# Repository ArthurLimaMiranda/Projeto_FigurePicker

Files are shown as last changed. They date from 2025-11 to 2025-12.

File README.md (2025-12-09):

# Projeto FigurePicker

Sistema integrado de visão computacional e controle robótico para identificação, classificação e manipulação de objetos geométricos (cubos e esferas).

## Visão Geral

O FigurePicker é um projeto de robótica que combina:
- **Visão Computacional**: Detecção e classificação de objetos usando YOLO e classificadores tradicionais
- **Simulação**: Ambiente virtual completo em CoppeliaSim com garra cartesiana (PPP)
- **Hardware**: Sistema de controle físico com ESP32 usando comunicação ESP-NOW

### Fluxo do Sistema
```mermaid
graph LR
    A[Câmera] --> B[YOLOv11<br/>Detecção]
    B --> C[Coordenadas<br/>3D]
    C --> D[ESP32<br/>Controle]
    D --> E[Garra<br/>Movimento]
```

## Estrutura do Projeto

```
Projeto_FigurePicker/
├── Garra/                 # Modelos 3D da garra
│   ├── tinker.obj        # Modelo 3D principal da garra
│   └── obj.mtl           # Arquivo de materiais
├── Hardware/              # Código para controle físico com ESP32
├── Simulation/            # Simulações em CoppeliaSim
│   ├── Entrega_11-11/    # Versão com câmera acoplada
│   └── Entrega_25-11/    # Versão com câmera externa
└── Vision_picker/         # Sistema de visão computacional
    ├── Classifier/        # Classificador tradicional (ML)
    ├── Coords/            # Extração de coordenadas
    ├── yolo_dataset/      # Scripts de preparação de dataset
    └── yolov11s/          # Modelo YOLO para detecção
```

## Componentes Principais

### 1. Garra (Modelos 3D)
Modelos 3D da garra utilizada no sistema:
- **tinker.obj**: Modelo 3D completo da garra cartesiana
- **obj.mtl**: Arquivo de materiais e texturas
- Formato OBJ para importação em simuladores (CoppeliaSim) e CAD

Garra - Modelo 3D
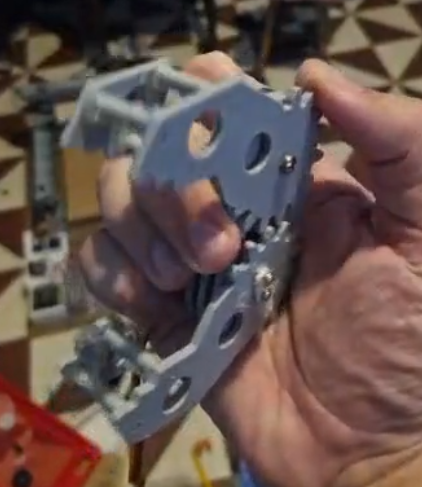
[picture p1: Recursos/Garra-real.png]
Garra - Versão Real


### 2. Hardware
Sistema de controle com dois ESP32 comunicando via ESP-NOW:
- ESP Principal: Controla movimento nos eixos X
- ESP Secundário: Controla movimentos nos eixos Y e Z
- Encoder para feedback de posição
- Interface serial para comandos

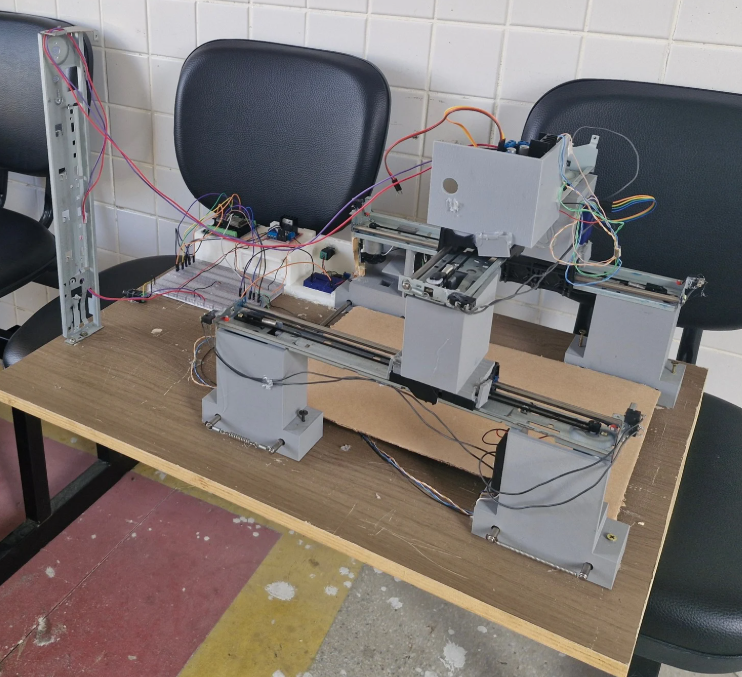
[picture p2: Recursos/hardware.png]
Demonstração do Hardware


Vídeo de demonstração do Hardware:

https://github.com/user-attachments/assets/e5667fb1-db5c-466d-99d5-b31783a8a168

### 3. Simulation
Simulações em CoppeliaSim com evolução do sistema:
- **V1 (11/11)**: Câmera acoplada à garra, controle por pixel
- **V2 (25/11)**: Câmera externa em tripé, raycasting 3D completo

https://github.com/user-attachments/assets/42683209-a07c-4944-ae0e-6913812d1ff3

### 4. Vision Picker
Sistema completo de visão computacional:
- **YOLOv11s**: Detecção em tempo real de cubos e esferas
- **Classifier**: Classificador tradicional baseado em características
- **Dataset Tools**: Scripts para preparação e augmentation de dados

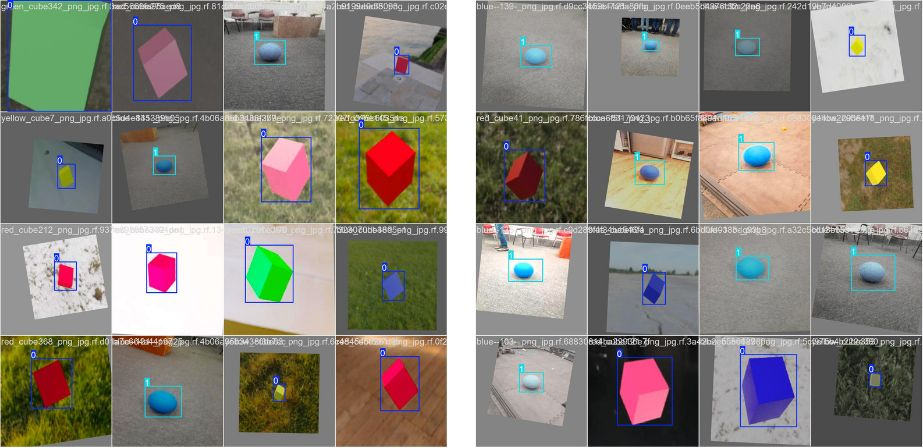
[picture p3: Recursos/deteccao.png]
Detecção de Cubos e Esferas


## Instalação

### Requisitos
- Python 3.8+
- Arduino IDE (para ESP32)
- CoppeliaSim (para simulações)

### Python Dependencies
```bash
pip install -r Vision_picker/requirements.txt
```

## Funcionalidades

- ✅ Detecção de objetos geométricos (cubos e esferas)
- ✅ Classificação de formas usando ML
- ✅ Cálculo de coordenadas 3D
- ✅ Simulação completa com raycasting
- ✅ Controle físico com feedback de encoder
- ✅ Comunicação wireless entre ESP32
- ✅ Dataset augmentation automático

## Uso

### Treinar Modelo YOLO
```bash
cd Vision_picker/yolov11s
python train.py
```

### Executar Detecção
```bash
cd Vision_picker/yolov11s
python inference_yolov11.py
```

### Classificar Imagem
```bash
cd Vision_picker/Classifier
python img_classifier.py
```

## Dataset

O projeto utiliza dataset customizado com:
- Cubos e esferas em diversas condições de iluminação
- Augmentation automático para balanceamento
- Divisão: 70% train / 20% val / 10% test

## Hardware Setup

1. Grave o código `MacFinder.ino` para identificar os endereços MAC
2. Atualize os endereços no código principal
3. Configure ESP Principal e Secundário
4. Conecte encoders e motores conforme pinout

## Documentação Detalhada

Cada pasta contém seu próprio README com detalhes específicos:
- [Hardware/README.md](Hardware/README.md) - Sistema físico, pinout, protocolo ESP-NOW
- [Simulation/Entrega_11-11/Readme.md](Simulation/Entrega_11-11/Readme.md) - Simulação V1 (câmera acoplada)
- [Simulation/Entrega_25-11/README.md](Simulation/Entrega_25-11/README.md) - Simulação V2 (raycasting 3D)
- [Vision_picker/README.md](Vision_picker/README.md) - Sistema de visão completo
- [Vision_picker/yolov11s/README.md](Vision_picker/yolov11s/README.md) - Treinamento e inferência YOLO
- [Vision_picker/Classifier/README.md](Vision_picker/Classifier/README.md) - Classificador tradicional ML

## Contribuidores

Projeto desenvolvido como parte do curso de Robótica.

## Histórico de Versões

- **25/11/2025**: Migração para câmera externa com raycasting 3D
- **11/11/2025**: Versão inicial com câmera acoplada
- **Dezembro/2025**: Integração completa visão + hardware

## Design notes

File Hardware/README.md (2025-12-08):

# Hardware - Sistema de Controle Físico

Sistema de controle robótico baseado em ESP32 com comunicação ESP-NOW para manipulação de garra cartesiana.

## Visão Geral

Este módulo implementa o controle físico da garra robótica usando dois microcontroladores ESP32 que se comunicam via protocolo ESP-NOW (comunicação wireless ponto-a-ponto).

## Estrutura

```
Hardware/
├── Macs.txt                          # Endereços MAC dos ESP32
├── MacFinder/
│   └── MacFinder.ino                # Utilitário para descobrir endereço MAC
├── MovimentacaoEspPrincipal/
│   └── MovimentacaoEspPrincipal.ino # Controle do ESP Principal (Eixo X)
├── MovimentacaoEspSecundaria/
│   └── MovimentacaoEspSecundaria.ino # Controle do ESP Secundário (Eixos Y e Z)
└── MovimentacaoIntegrado/
    └── MovimentacaoIntegrado.ino    # Versão integrada (legacy)
```

## Arquitetura do Sistema

### Topologia de Comunicação

```
┌─────────────────────────┐
│   ESP Principal         │
│   (Eixo X)              │
│   MAC: a0:dd:6c:85:8a:b8│
└───────────┬─────────────┘
            │ ESP-NOW
            │ (Wireless)
            ▼
┌─────────────────────────┐
│   ESP Secundário        │
│   (Eixos Y e Z)         │
│   MAC: a0:dd:6c:03:e7:b8│
└─────────────────────────┘
```

## Hardware Components

### ESP Principal
- **Função**: Controla movimento no eixo X (Frente/Trás)
- **Motores**: 2 motores DC (Motor A e Motor B)
- **Encoder**: Encoder rotativo para feedback de posição
- **Comunicação**: Serial + ESP-NOW

#### Pinout ESP Principal
```
Motores:
- IN1 (GPIO 32): Motor A - Sentido 1
- IN2 (GPIO 33): Motor A - Sentido 2
- IN3 (GPIO 12): Motor B - Sentido 1
- IN4 (GPIO 13): Motor B - Sentido 2

Encoder:
- CLK (GPIO 14): Canal A do encoder
- DT (GPIO 27): Canal B do encoder

Botões:
- BTN_UP (GPIO 18): Movimento para frente
- BTN_DOWN (GPIO 19): Movimento para trás
```

### ESP Secundário
- **Função**: Controla movimentos nos eixos Y (Esquerda/Direita) e Z (Subir/Descer)
- **Motores**: 4 motores DC (2 para Y, 2 para Z)
- **Encoders**: 2 encoders (um para cada eixo)
- **Comunicação**: ESP-NOW (recebe comandos do ESP Principal)

## Protocolo ESP-NOW

### Estrutura de Mensagem
```cpp
typedef struct struct_message {
    char command[10];  // Comando: "MOVEY", "MOVEZ", "RESET", etc.
    long value;        // Valor associado (ex: direção)
    long position;     // Posição alvo (para movimentos absolutos)
} struct_message;
```

### Comandos Disponíveis

#### Comandos Locais (ESP Principal)
- `FRONT` / `F`: Move para frente
- `BACK` / `B`: Move para trás
- `STOPX`: Para motores do eixo X
- `RESETX`: Reseta encoder do eixo X
- `GOTOX <pos>`: Move para posição absoluta no eixo X
- `STATUS`: Exibe status dos encoders

#### Comandos Remotos (Enviados ao ESP Secundário)
- `MOVEY <dir>`: Move no eixo Y (1=direita, -1=esquerda)
- `MOVEZ <dir>`: Move no eixo Z (1=subir, -1=descer)
- `STOPY`: Para motores do eixo Y
- `STOPZ`: Para motores do eixo Z
- `RESETY`: Reseta encoder do eixo Y
- `RESETZ`: Reseta encoder do eixo Z
- `GOTOY <pos>`: Move para posição absoluta no eixo Y
- `GOTOZ <pos>`: Move para posição absoluta no eixo Z

## Setup e Configuração

### 1. Descobrir Endereços MAC

Primeiro, descubra os endereços MAC dos seus ESP32:

```bash
# Grave MacFinder.ino em cada ESP32
# Abra o Serial Monitor (115200 baud)
# Anote os endereços MAC exibidos
```

### 2. Configurar Endereços

Edite os arquivos `.ino` com os MACs corretos:

**MovimentacaoEspPrincipal.ino:**
```cpp
// MAC do ESP Secundário
uint8_t broadcastAddress[] = {0xA0, 0xDD, 0x6C, 0x03, 0xE7, 0xB8};
```

**MovimentacaoEspSecundaria.ino:**
```cpp
// MAC do ESP Principal (se necessário para resposta)
uint8_t broadcastAddress[] = {0xA0, 0xDD, 0x6C, 0x85, 0x8A, 0xB8};
```

### 3. Upload do Código

1. Instale a biblioteca ESP-NOW (já incluída no Arduino ESP32)
2. Grave `MovimentacaoEspPrincipal.ino` no ESP Principal
3. Grave `MovimentacaoEspSecundaria.ino` no ESP Secundário

### 4. Conexão Serial

Conecte ao ESP Principal via Serial (115200 baud) para enviar comandos.

## Interface Serial

### Comandos Disponíveis
```
Comandos do Eixo X (Local):
  FRONT ou F         - Move para frente
  BACK ou B          - Move para trás  
  STOPX              - Para motores X
  RESETX             - Reseta encoder X
  GOTOX <posicao>    - Move para posição absoluta X

Comandos dos Eixos Y e Z (Remoto):
  MOVEY <dir>        - Move Y (1=direita, -1=esquerda)
  MOVEZ <dir>        - Move Z (1=subir, -1=descer)
  STOPY              - Para motores Y
  STOPZ              - Para motores Z
  RESETY             - Reseta encoder Y
  RESETZ             - Reseta encoder Z
  GOTOY <posicao>    - Move para posição absoluta Y
  GOTOZ <posicao>    - Move para posição absoluta Z

Comandos Gerais:
  STATUS             - Mostra status dos encoders
  HELP ou ?          - Mostra esta ajuda
```

## Encoders

### Sistema de Feedback

Cada encoder fornece feedback em tempo real da posição:
- **Resolução**: Incremental (pulsos por rotação)
- **Tipo**: Encoder rotativo quadratura
- **Função**: Controle de posição absoluta e relativa

### Leitura de Encoder
```cpp
struct EncoderData {
    volatile long counter;
    volatile int lastStateA;
    int pinA;
    int pinB;
};
```

## Características

### Controle de Motores
- ✅ Controle de direção via ponte H
- ✅ Movimento suave com PWM (opcional)
- ✅ Proteção contra comandos simultâneos
- ✅ Delay configurável entre comandos

### Sistema de Segurança
- ✅ Debouncing em botões físicos
- ✅ Timeout entre comandos (10 segundos padrão)
- ✅ Confirmação de envio ESP-NOW
- ✅ Status de comunicação

### Feedback
- ✅ Posição em tempo real via encoder
- ✅ Status de comunicação ESP-NOW
- ✅ Confirmação de comandos recebidos
- ✅ Indicação de movimentos ativos

## Troubleshooting

### ESP-NOW não conecta
1. Verifique os endereços MAC
2. Certifique-se que ambos ESPs estão ligados
3. Verifique distância (máx ~100m em campo aberto)

### Encoder não conta
1. Verifique conexões dos pinos CLK e DT
2. Teste com movimento manual
3. Verifique interrupções ativadas

### Motores não respondem
1. Verifique alimentação dos motores
2. Teste ponte H separadamente
3. Verifique pinout IN1-IN4

## Especificações Técnicas

- **Microcontrolador**: ESP32
- **Frequência**: 240 MHz (dual core)
- **Comunicação**: ESP-NOW (2.4 GHz)
- **Alcance**: ~100 metros (linha de visão)
- **Latência**: <10ms
- **Baudrate Serial**: 115200

## Fluxo de Operação

1. ESP Principal recebe comando via Serial ou botão
2. Se comando local (X): executa diretamente
3. Se comando remoto (Y/Z): envia via ESP-NOW para secundário
4. ESP Secundário recebe e executa comando
5. Feedback via encoder em ambos ESPs
6. Status retornado ao usuário

## Notas de Desenvolvimento

- Delay de 10 segundos entre comandos pode ser ajustado em `COMMAND_DELAY`
- Encoders usam interrupções para precisão máxima
- Comunicação ESP-NOW é assíncrona
- Serial Monitor mostra debug completo

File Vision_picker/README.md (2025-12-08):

# Vision Picker - Sistema de Visão Computacional

Sistema completo de visão computacional para detecção, classificação e localização de objetos geométricos (cubos e esferas).

## Visão Geral

O módulo Vision Picker implementa duas abordagens complementares para processamento de imagens:
1. **YOLOv11s**: Detecção em tempo real de objetos
2. **Classificador Tradicional**: Classificação baseada em características extraídas

## Estrutura

```
Vision_picker/
├── requirements.txt              # Dependências Python
├── Classifier/                   # Classificador tradicional ML
│   ├── img_classifier.py        # Script de classificação
│   ├── train_classifier.py      # Treinamento do modelo
│   └── models/
│       └── model_params.json    # Parâmetros do modelo
├── Coords/                       # Extração de coordenadas
│   └── get_pos.py               # Detecção e posicionamento
├── yolo_dataset/                 # Preparação de dataset
│   ├── augmentation_com_labels.py
│   ├── converter_heic_para_jpg.py
│   ├── converter_labelme_to_yolo.py
│   ├── preparar_anotacao_final.py
│   ├── remover_heic.py
│   └── split_train_val.py
└── yolov11s/                     # Modelo YOLO
    ├── train.py                 # Treinamento YOLOv11s
    ├── inference_yolov11.py     # Inferência e detecção
    └── runs/                    # Resultados de treinamento
        └── detect/
            └── cubes_spheres_yolo11s/
```

## Instalação

### Requisitos
- Python 3.8 ou superior
- CUDA (opcional, para GPU)
- Webcam ou câmera USB (para detecção em tempo real)

### Instalação de Dependências

```bash
cd Vision_picker
pip install -r requirements.txt
```

### Dependências Principais
- `ultralytics>=8.0.0` - Framework YOLO
- `opencv-python` - Processamento de imagens
- `torch` + `torchvision` - Deep Learning
- `roboflow` - Download de datasets
- `scikit-learn` - Machine Learning tradicional
- `matplotlib` + `seaborn` - Visualização

## Componentes

### 1. YOLOv11s - Detecção em Tempo Real

Modelo de detecção de objetos baseado em YOLOv11 small, treinado especificamente para cubos e esferas.

#### Treinamento
```bash
cd yolov11s
python train.py
```

**Características do Treinamento:**
- Dataset do Roboflow (workspace: w0, project: 3d-geom-shape-detector)
- Filtragem automática: mantém apenas cubos e esferas
- Divisão: 70% train / 20% val / 10% test
- Augmentation para balanceamento de classes
- 150 épocas, batch size 16, imagem 640x640

#### Inferência
```bash
cd yolov11s
python inference_yolov11.py
```

**Funcionalidades:**
- Detecção em tempo real via webcam
- Suporte a imagens e vídeos
- Bounding boxes com confidence score
- Contagem de objetos por classe
- Salvamento de resultados

### 2. Classificador Tradicional

Classificador baseado em Machine Learning tradicional usando características extraídas das imagens.

#### Treinamento
```bash
cd Classifier
python train_classifier.py
```

**Pipeline:**
1. Carregamento de dataset
2. Extração de características (cor, forma, textura)
3. Treinamento de classificador (SVM, Random Forest, etc.)
4. Validação e salvamento do modelo

#### Classificação
```bash
cd Classifier
python img_classifier.py
```

**Processo:**
1. Seleção de imagem via dialog
2. Pré-processamento (resize para 64x64)
3. Extração de características
4. Predição da classe
5. Exibição do resultado

### 3. Sistema de Coordenadas

Extração de posição e coordenadas de objetos detectados.

```bash
cd Coords
python get_pos.py
```

**Funcionalidades:**
- Detecção de contornos
- Cálculo de centróides
- Classificação de formas
- Estimativa de distâncias
- Visualização com matplotlib

### 4. Dataset Tools

Scripts para preparação e augmentation de datasets.

#### Conversão de Formatos
```bash
cd yolo_dataset
python converter_heic_para_jpg.py    # HEIC → JPG
python converter_labelme_to_yolo.py  # LabelMe → YOLO
```

#### Preparação de Dataset
```bash
python preparar_anotacao_final.py    # Preparação final
python split_train_val.py            # Divisão train/val/test
```

#### Data Augmentation
```bash
python augmentation_com_labels.py    # Augmentation com labels
```

**Transformações Aplicadas:**
- Horizontal/Vertical Flip
- Rotação (±15°)
- Random Scale (±20%)
- Brightness/Contrast adjustment
- Hue/Saturation/Value shifts
- Gaussian Noise + Blur
- Motion Blur
- Coarse Dropout

## Uso Típico

### Pipeline Completo

1. **Preparar Dataset**
   ```bash
   cd yolo_dataset
   python converter_heic_para_jpg.py
   python converter_labelme_to_yolo.py
   python split_train_val.py
   python augmentation_com_labels.py
   ```

2. **Treinar YOLO**
   ```bash
   cd ../yolov11s
   python train.py
   ```

3. **Executar Detecção**
   ```bash
   python inference_yolov11.py
   ```

4. **Obter Coordenadas**
   ```bash
   cd ../Coords
   python get_pos.py
   ```

## Resultados e Métricas

### YOLOv11s
- **mAP@0.5**: ~0.95+ (após 150 épocas)
- **Precision**: ~0.93+
- **Recall**: ~0.92+
- **FPS**: 30-60 (GPU) / 5-10 (CPU)

### Classificador Tradicional
- **Accuracy**: ~0.85-0.90
- **Tamanho**: 64x64 pixels
- **Features**: Cor RGB flattened (12288 features)

## 🔧 Configuração

### Dataset YOLO (train.py)
```python
API_KEY = "sua_chave_roboflow"
WORKSPACE = "w0"
PROJECT = "3d-geom-shape-detector"
VERSION = 1

TRAIN_PCT = 70
VAL_PCT = 20
TEST_PCT = 10

EPOCHS = 150
BATCH_SIZE = 16
IMG_SIZE = 640
```

### Classificador (img_classifier.py)
```python
IMG_SIZE = (64, 64)
LABEL_MAP = {0: "cubo", 1: "esfera"}
MODEL_PATH = '../Classifier/models/melhor_modelo.pkl'
```

## Visualização

### Detecção YOLO
- Bounding boxes coloridas por classe
- Confidence scores exibidos
- Contagem de objetos em tempo real
- Salvamento automático de frames

### Classificador
- Imagem com label predito
- Texto overlay com classe
- Display em janela OpenCV

## Troubleshooting

### CUDA não disponível
```python
# Força CPU
DEVICE = 'cpu'
```

### Erro de memória no treinamento
```python
# Reduz batch size
BATCH_SIZE = 8
```

### Dataset vazio após filtragem
```python
# Verifica labels no dataset
# Certifica-se que existem anotações para cubos/esferas
```

### Modelo não carrega
```bash
# Verifica caminho do modelo
ls Classifier/models/
ls yolov11s/runs/detect/
```

## Estrutura do Dataset

### Formato YOLO
```
dataset/
├── images/
│   ├── train/
│   ├── val/
│   └── test/
└── labels/
    ├── train/
    ├── val/
    └── test/
```

### Formato de Label (.txt)
```
<class_id> <x_center> <y_center> <width> <height>
```
Valores normalizados entre 0 e 1.

## Algoritmos Implementados

### Detecção de Objetos
- **YOLOv11s**: Arquitetura CSPDarknet + PANet + YOLOv11 head
- **Anchor-free**: Sem anchor boxes pré-definidos
- **Multi-scale**: Detecção em múltiplas escalas

### Classificação
- **Feature Extraction**: RGB flattening
- **Classifiers**: SVM, Random Forest, KNN
- **Preprocessing**: Resize + Normalization

### Segmentação
- **Color-based**: HSV thresholding
- **Contour detection**: findContours OpenCV
- **Shape analysis**: Aproximação poligonal

## Casos de Uso

1. **Robótica**: Pick-and-place de objetos
2. **Controle de Qualidade**: Inspeção de peças
3. **Contagem**: Inventário automático
4. **Sorting**: Separação por forma/cor

## Notas Importantes

- ⚠️ Modelo YOLO requer GPU para treinamento eficiente
- ⚠️ Dataset augmentation aumenta significativamente o tempo de preparação
- ⚠️ Classificador tradicional é mais rápido mas menos preciso que YOLO
- ⚠️ Webcam deve ter boa iluminação para melhores resultados

## Workflow Recomendado

```mermaid
graph LR
    A[Captura Imagens] --> B[Anotação]
    B --> C[Conversão YOLO]
    C --> D[Augmentation]
    D --> E[Treinamento]
    E --> F[Validação]
    F --> G[Inferência]
    G --> H[Coordenadas]
    H --> I[Controle Robô]
```

## Exemplos de Saída

### Detecção YOLO
```
Frame 1:
  - Cubo: 2 objetos detectados
  - Esfera: 1 objeto detectado
  - Confidence média: 0.94
```

### Classificação
```
Imagem: objeto_01.jpg
Classe predita: Cubo
Confidence: 0.89
```

### Coordenadas
```
Objeto 1:
  - Tipo: Cubo
  - Centro: (320, 240)
  - Área: 4500 px²
  - Distância: 45.2 cm
```

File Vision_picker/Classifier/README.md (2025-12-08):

# Classifier - Classificador Tradicional de Formas

Sistema de classificação de formas geométricas usando Machine Learning tradicional baseado em características extraídas de imagens.

## Visão Geral

Este módulo implementa um classificador binário para distinguir entre cubos e esferas usando técnicas de Machine Learning clássicas (não deep learning). O classificador é treinado com características extraídas diretamente dos pixels das imagens.

## Estrutura

```
Classifier/
├── img_classifier.py         # Script de classificação de imagens
├── train_classifier.py       # Script de treinamento do modelo
└── models/
    ├── melhor_modelo.pkl     # Modelo treinado serializado
    └── model_params.json     # Parâmetros e configurações
```

## Instalação

### Dependências
```bash
pip install numpy scikit-image scikit-learn matplotlib seaborn joblib opencv-python
```

## Funcionamento

### Pipeline de Classificação

1. **Carregamento de Imagem**
   - Leitura via OpenCV
   - Conversão de cores (BGR → RGB ou Grayscale)

2. **Pré-processamento**
   - Redimensionamento para 64x64 pixels
   - Normalização (opcional)
   - Flatten (conversão para vetor 1D)

3. **Extração de Características**
   - RGB: 64 × 64 × 3 = 12,288 features
   - Grayscale: 64 × 64 = 4,096 features

4. **Predição**
   - Carregamento do modelo treinado (.pkl)
   - Classificação usando modelo sklearn
   - Retorno da classe predita

## Uso

### Classificar Imagem

```bash
python img_classifier.py
```

**Fluxo:**
1. Abre diálogo de seleção de arquivo
2. Carrega imagem selecionada
3. Processa e classifica
4. Exibe resultado com label sobreposto

### Treinar Modelo

```bash
python train_classifier.py
```

**Parâmetros configuráveis:**
```python
IMG_SIZE = (64, 64)           # Tamanho das imagens
USE_COLOR = True              # True=RGB, False=Grayscale
CLASSIFIER = 'SVM'            # 'SVM', 'RandomForest', 'KNN'
TEST_SIZE = 0.2               # Porcentagem para teste
RANDOM_STATE = 42             # Seed para reprodutibilidade
```

## Características Técnicas

### Extração de Features

#### Modo RGB (Padrão)
```python
IMG_SIZE = (64, 64)
CHANNELS = 3
TOTAL_FEATURES = 64 × 64 × 3 = 12,288
```

Cada pixel contribui com 3 valores (R, G, B).

#### Modo Grayscale
```python
IMG_SIZE = (64, 64)
CHANNELS = 1
TOTAL_FEATURES = 64 × 64 = 4,096
```

Cada pixel contribui com 1 valor (intensidade).

### Classificadores Suportados

#### 1. SVM (Support Vector Machine)
```python
from sklearn.svm import SVC
model = SVC(kernel='rbf', C=1.0, gamma='scale')
```
- **Pros**: Ótimo para alta dimensionalidade, robusto
- **Contras**: Lento com datasets grandes

#### 2. Random Forest
```python
from sklearn.ensemble import RandomForestClassifier
model = RandomForestClassifier(n_estimators=100, max_depth=10)
```
- **Pros**: Rápido, interpretável, robusto a overfitting
- **Contras**: Pode consumir mais memória

#### 3. K-Nearest Neighbors
```python
from sklearn.neighbors import KNeighborsClassifier
model = KNeighborsClassifier(n_neighbors=5)
```
- **Pros**: Simples, sem treinamento
- **Contras**: Lento em inferência, sensível a ruído

## Métricas de Avaliação

### Métricas Calculadas
```python
from sklearn.metrics import accuracy_score, precision_score, recall_score, f1_score

accuracy = accuracy_score(y_true, y_pred)
precision = precision_score(y_true, y_pred)
recall = recall_score(y_true, y_pred)
f1 = f1_score(y_true, y_pred)
```

### Matriz de Confusão
```python
from sklearn.metrics import confusion_matrix
import seaborn as sns

cm = confusion_matrix(y_true, y_pred)
sns.heatmap(cm, annot=True, fmt='d')
```

## Visualização

### Exibição de Resultado

```python
# Carrega imagem
img_display = cv2.imread(image_path)

# Adiciona label predito
label_text = f"Class: {label_map.get(prediction)}"
cv2.putText(img_display, label_text, (10, 30), 
           cv2.FONT_HERSHEY_SIMPLEX, 1, (0, 255, 0), 2)

# Mostra imagem
cv2.imshow("Classification Result", img_display)
cv2.waitKey(0)
```

## Configuração

### img_classifier.py

```python
# Configurações principais
IMG_SIZE = (64, 64)                    # Tamanho de redimensionamento
LABEL_MAP = {0: "cubo", 1: "esfera"}   # Mapeamento de classes
MODEL_PATH = 'models/melhor_modelo.pkl' # Caminho do modelo

# Modo de cor
USE_COLOR = True  # True=RGB, False=Grayscale
```

### train_classifier.py

```python
# Dataset
DATASET_PATH = 'data/'
CLASSES = ['cubo', 'esfera']

# Hyperparameters
IMG_SIZE = (64, 64)
TEST_SIZE = 0.2
VALIDATION_SIZE = 0.1
RANDOM_STATE = 42

# Modelo
CLASSIFIER_TYPE = 'SVM'  # 'SVM', 'RandomForest', 'KNN'

# Salvamento
MODEL_SAVE_PATH = 'models/melhor_modelo.pkl'
PARAMS_SAVE_PATH = 'models/model_params.json'
```

## Estrutura do Dataset

### Organização Esperada
```
data/
├── cubo/
│   ├── cubo_001.jpg
│   ├── cubo_002.jpg
│   └── ...
└── esfera/
    ├── esfera_001.jpg
    ├── esfera_002.jpg
    └── ...
```

### Formato das Imagens
- **Formatos suportados**: JPG, PNG, JPEG
- **Tamanho**: Qualquer (será redimensionado)
- **Cor**: RGB ou Grayscale

## Exemplos de Uso

### Exemplo 1: Classificação Simples
```python
import cv2
import joblib

# Carrega modelo
model = joblib.load('models/melhor_modelo.pkl')

# Carrega e processa imagem
image = cv2.imread('test_image.jpg')
image = cv2.cvtColor(image, cv2.COLOR_BGR2RGB)
image_resized = cv2.resize(image, (64, 64))
image_flat = image_resized.flatten()

# Classifica
prediction = model.predict([image_flat])[0]
label = {0: "cubo", 1: "esfera"}[prediction]

print(f"Classe predita: {label}")
```

### Exemplo 2: Batch Classification
```python
import os
from glob import glob

# Carrega modelo
model = joblib.load('models/melhor_modelo.pkl')

# Processa múltiplas imagens
image_paths = glob('test_images/*.jpg')
results = []

for path in image_paths:
    image = cv2.imread(path)
    image = cv2.cvtColor(image, cv2.COLOR_BGR2RGB)
    image_resized = cv2.resize(image, (64, 64))
    image_flat = image_resized.flatten()
    
    prediction = model.predict([image_flat])[0]
    results.append({
        'path': path,
        'class': {0: "cubo", 1: "esfera"}[prediction]
    })

# Mostra resultados
for result in results:
    print(f"{result['path']}: {result['class']}")
```

## Análise de Performance

### Vantagens
✅ **Rápido**: Inferência em milissegundos  
✅ **Leve**: Modelo pequeno (~1-10 MB)  
✅ **Simples**: Fácil de entender e debugar  
✅ **Sem GPU**: Roda em qualquer CPU  
✅ **Interpretável**: Features são pixels diretamente  

### Limitações
❌ **Menor Precisão**: Tipicamente 85-90% vs 95%+ do YOLO  
❌ **Sensível a Ruído**: Pixels brutos são afetados por iluminação  
❌ **Sem Localização**: Apenas classifica, não detecta posição  
❌ **Features Fixas**: Não aprende features automaticamente  
❌ **Escala Limitada**: Funciona bem apenas em imagens simples  

## Troubleshooting

### Modelo não encontrado
```python
# Verifica se o arquivo existe
import os
if not os.path.exists('models/melhor_modelo.pkl'):
    print("Modelo não encontrado! Execute train_classifier.py primeiro.")
```

### Erro de dimensão
```python
# Certifica-se que a imagem está no formato correto
print(f"Shape esperada: {64 * 64 * 3} para RGB")
print(f"Shape recebida: {image_flat.shape}")
```

### Baixa acurácia
- Aumentar tamanho do dataset
- Adicionar data augmentation
- Experimentar diferentes classificadores
- Ajustar hiperparâmetros
- Considerar usar features mais sofisticadas (HOG, SIFT, etc.)

## Recursos Adicionais

### Melhorias Possíveis

1. **Feature Engineering**
   - HOG (Histogram of Oriented Gradients)
   - SIFT (Scale-Invariant Feature Transform)
   - Color histograms
   - Texture features (LBP)

2. **Ensemble Methods**
   - Voting classifier
   - Stacking
   - Boosting (XGBoost, LightGBM)

3. **Preprocessing**
   - Normalização
   - Equalização de histograma
   - Remoção de background
   - Edge detection

## Comparação: Classifier vs YOLO

| Aspecto | Classifier | YOLOv11s |
|---|---|---|
| **Precisão** | 85-90% | 95%+ |
| **Velocidade** | ~5-10ms | ~20-50ms |
| **Tamanho** | 1-10 MB | 20-50 MB |
| **Localização** | ❌ Não | ✅ Sim |
| **Multiple Objects** | ❌ Não | ✅ Sim |
| **GPU Required** | ❌ Não | ⚠️ Recomendado |
| **Treinamento** | Minutos | Horas |
| **Dataset Size** | 100-1000 | 1000-10000+ |

## Notas

- O classificador funciona melhor com imagens centradas e recortadas
- Iluminação consistente é crucial para boa performance
- Para produção, considere usar YOLO para detecção + este classificador para refinamento
- Modelo .pkl é específico da versão do sklearn - recrie se necessário

## Workflow Típico

```bash
# 1. Coletar e organizar dataset
mkdir -p data/cubo data/esfera

# 2. Treinar modelo
python train_classifier.py

# 3. Testar classificação
python img_classifier.py

# 4. Avaliar resultados e iterar
```

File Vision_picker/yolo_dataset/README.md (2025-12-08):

# YOLO Dataset Tools - Preparação e Augmentation

Conjunto de scripts para preparação, conversão e augmentation de datasets para treinamento de modelos YOLO.

## Visão Geral

Este módulo contém ferramentas essenciais para preparar datasets de imagens para treinamento de modelos YOLO, incluindo conversão de formatos, organização de dados, data augmentation e validação de labels.

## Estrutura

```
yolo_dataset/
├── augmentation_com_labels.py          # Augmentation preservando labels YOLO
├── converter_heic_para_jpg.py          # Converte HEIC → JPG
├── converter_labelme_to_yolo.py        # Converte LabelMe → YOLO
├── preparar_anotacao_final.py          # Preparação final do dataset
├── remover_heic.py                     # Remove arquivos HEIC após conversão
└── split_train_val.py                  # Divide dataset em train/val/test
```

## Instalação

### Dependências
```bash
pip install opencv-python pillow pillow-heif albumentations pyyaml numpy
```

## Scripts Disponíveis

### 1. converter_heic_para_jpg.py

Converte imagens do formato HEIC (usado por iPhones) para JPG.

#### Uso
```bash
python converter_heic_para_jpg.py
```

#### Funcionalidades
- ✅ Busca recursiva por arquivos .heic e .HEIC
- ✅ Conversão com preservação de qualidade
- ✅ Mantém estrutura de diretórios
- ✅ Log de progresso

#### Código Base
```python
from PIL import Image
import pillow_heif

pillow_heif.register_heif_opener()

heic_image = Image.open('image.heic')
heic_image.convert('RGB').save('image.jpg', 'JPEG', quality=95)
```

---

### 2. remover_heic.py

Remove arquivos HEIC após conversão bem-sucedida.

#### Uso
```bash
python remover_heic.py
```

⚠️ **Atenção**: Use apenas após confirmar que as conversões foram bem-sucedidas!

#### Funcionalidades
- ✅ Busca recursiva por .heic/.HEIC
- ✅ Confirmação antes de deletar
- ✅ Log de arquivos removidos
- ✅ Contagem de espaço liberado

---

### 3. converter_labelme_to_yolo.py

Converte anotações do formato LabelMe (JSON) para formato YOLO (TXT).

#### Formato LabelMe (JSON)
```json
{
  "imagePath": "image.jpg",
  "imageHeight": 480,
  "imageWidth": 640,
  "shapes": [
    {
      "label": "cubo",
      "points": [[x1, y1], [x2, y2], [x3, y3], [x4, y4]],
      "shape_type": "polygon"
    }
  ]
}
```

#### Formato YOLO (TXT)
```
<class_id> <x_center> <y_center> <width> <height>
```
Valores normalizados entre 0 e 1.

#### Uso
```bash
python converter_labelme_to_yolo.py
```

#### Conversão
```python
# LabelMe polygon → YOLO bounding box
x_min, y_min = min(points, key=lambda p: p[0])[0], min(points, key=lambda p: p[1])[1]
x_max, y_max = max(points, key=lambda p: p[0])[0], max(points, key=lambda p: p[1])[1]

# Normaliza
x_center = ((x_min + x_max) / 2) / img_width
y_center = ((y_min + y_max) / 2) / img_height
width = (x_max - x_min) / img_width
height = (y_max - y_min) / img_height

# Formato YOLO
yolo_label = f"{class_id} {x_center} {y_center} {width} {height}"
```

---

### 4. split_train_val.py

Divide dataset em conjuntos de treino, validação e teste.

#### Uso
```bash
python split_train_val.py
```

#### Configuração
```python
TRAIN_RATIO = 0.7   # 70% treino
VAL_RATIO = 0.2     # 20% validação
TEST_RATIO = 0.1    # 10% teste
```

#### Estrutura de Saída
```
dataset/
├── images/
│   ├── train/
│   ├── val/
│   └── test/
└── labels/
    ├── train/
    ├── val/
    └── test/
```

#### Funcionalidades
- ✅ Split aleatório com seed fixo
- ✅ Mantém pareamento imagem-label
- ✅ Validação de integridade
- ✅ Relatório de estatísticas

---

### 5. augmentation_com_labels.py

Aplica data augmentation preservando as anotações YOLO.

#### Uso
```bash
python augmentation_com_labels.py
```

#### Transformações Aplicadas

```python
import albumentations as A

transform = A.Compose([
    # Flips
    A.HorizontalFlip(p=0.5),
    A.VerticalFlip(p=0.2),
    
    # Geometric
    A.Rotate(limit=15, border_mode=cv2.BORDER_CONSTANT, value=0, p=0.5),
    A.RandomScale(scale_limit=0.2, p=0.3),
    
    # Color
    A.RandomBrightnessContrast(brightness_limit=0.2, contrast_limit=0.2, p=0.5),
    A.HueSaturationValue(hue_shift_limit=20, sat_shift_limit=30, val_shift_limit=20, p=0.5),
    A.RGBShift(r_shift_limit=20, g_shift_limit=20, b_shift_limit=20, p=0.3),
    
    # Noise
    A.GaussNoise(var_limit=(10.0, 50.0), p=0.3),
    A.GaussianBlur(blur_limit=(3, 7), p=0.3),
    A.MotionBlur(blur_limit=7, p=0.2),
    
    # Dropout
    A.CoarseDropout(max_holes=8, max_height=32, max_width=32, p=0.3),
    
], bbox_params=A.BboxParams(
    format='albumentations',  # [x_min, y_min, x_max, y_max]
    label_fields=['class_labels'],
    min_area=16,
    min_visibility=0.3
))
```

#### Parâmetros
```python
IMAGES_DIR = 'images/train'
LABELS_DIR = 'labels/train'
OUTPUT_DIR = 'augmented_dataset'
AUGMENTATIONS_PER_IMAGE = 5  # Gera 5 variações por imagem
```

#### Funcionalidades
- ✅ Preserva bounding boxes durante transformações
- ✅ Remove boxes com área mínima < threshold
- ✅ Remove boxes com visibilidade < threshold
- ✅ Nomenclatura automática (img_001_aug_0.jpg)
- ✅ Validação de labels YOLO

---

### 6. preparar_anotacao_final.py

Script de preparação final do dataset antes do treinamento.

#### Uso
```bash
python preparar_anotacao_final.py
```

#### Funcionalidades
- ✅ Validação de integridade (pareamento img-label)
- ✅ Verificação de labels vazios
- ✅ Normalização de nomes de arquivo
- ✅ Criação de data.yaml
- ✅ Estatísticas do dataset
- ✅ Visualização de exemplos

#### Validações Realizadas
```python
# 1. Cada imagem tem um label
# 2. Cada label tem uma imagem
# 3. Labels não estão vazios
# 4. Coordenadas estão normalizadas (0-1)
# 5. Class IDs são válidos
# 6. Bounding boxes estão dentro da imagem
```

---

## Workflow Completo

### Pipeline Recomendado

```bash
# 1. Converter HEIC para JPG
python converter_heic_para_jpg.py

# 2. Remover arquivos HEIC originais
python remover_heic.py

# 3. Converter anotações LabelMe para YOLO
python converter_labelme_to_yolo.py

# 4. Dividir em train/val/test
python split_train_val.py

# 5. Aplicar augmentation
python augmentation_com_labels.py

# 6. Preparação final e validação
python preparar_anotacao_final.py

# 7. Treinar modelo (no diretório yolov11s)
cd ../yolov11s
python train.py
```

---

## Estruturas de Dataset

### Antes do Processamento
```
raw_data/
├── image_001.heic
├── image_001.json  (LabelMe)
├── image_002.heic
└── image_002.json
```

### Após Conversão
```
converted/
├── image_001.jpg
├── image_001.txt  (YOLO)
├── image_002.jpg
└── image_002.txt
```

### Após Split
```
dataset/
├── images/
│   ├── train/  (70%)
│   ├── val/    (20%)
│   └── test/   (10%)
└── labels/
    ├── train/
    ├── val/
    └── test/
```

### Após Augmentation
```
augmented_dataset/
├── images/
│   └── train/
│       ├── img_001.jpg
│       ├── img_001_aug_0.jpg
│       ├── img_001_aug_1.jpg
│       └── ...
└── labels/
    └── train/
        ├── img_001.txt
        ├── img_001_aug_0.txt
        ├── img_001_aug_1.txt
        └── ...
```

---

## Exemplos de Uso

### Exemplo 1: Conversão Completa

```python
from pathlib import Path
import subprocess

# 1. Converter HEIC
subprocess.run(['python', 'converter_heic_para_jpg.py'])

# 2. Converter Labels
subprocess.run(['python', 'converter_labelme_to_yolo.py'])

# 3. Split dataset
subprocess.run(['python', 'split_train_val.py'])

print("Dataset preparado!")
```

### Exemplo 2: Augmentation Customizado

```python
import albumentations as A
import cv2
import numpy as np

def custom_augmentation(image, boxes, labels):
    transform = A.Compose([
        A.HorizontalFlip(p=0.5),
        A.Rotate(limit=10, p=0.3),
        A.RandomBrightnessContrast(p=0.5),
    ], bbox_params=A.BboxParams(
        format='yolo',
        label_fields=['class_labels']
    ))
    
    augmented = transform(image=image, bboxes=boxes, class_labels=labels)
    return augmented['image'], augmented['bboxes'], augmented['class_labels']
```

### Exemplo 3: Validação de Labels

```python
def validate_yolo_label(label_path, img_width, img_height):
    """Valida formato YOLO"""
    with open(label_path, 'r') as f:
        for line in f:
            parts = line.strip().split()
            if len(parts) != 5:
                return False, "Formato inválido"
            
            cls_id, x, y, w, h = map(float, parts)
            
            # Verifica normalização
            if not (0 <= x <= 1 and 0 <= y <= 1 and 0 <= w <= 1 and 0 <= h <= 1):
                return False, "Coordenadas fora do range [0, 1]"
            
            # Verifica box dentro da imagem
            x1, y1 = x - w/2, y - h/2
            x2, y2 = x + w/2, y + h/2
            
            if x1 < 0 or y1 < 0 or x2 > 1 or y2 > 1:
                return False, "Bounding box fora da imagem"
    
    return True, "OK"
```

---

## Troubleshooting

### Erro: HEIC não suportado
```bash
pip install pillow-heif
```

### Labels não convertendo
```python
# Verifica formato JSON
import json
with open('label.json', 'r') as f:
    data = json.load(f)
    print(data.keys())  # Deve ter 'shapes'
```

### Augmentation quebrando labels
```python
# Aumenta min_visibility e min_area
bbox_params=A.BboxParams(
    format='yolo',
    min_area=100,      # Aumentado de 16
    min_visibility=0.5  # Aumentado de 0.3
)
```

### Dataset desbalanceado após split
```python
# Usa stratified split
from sklearn.model_selection import train_test_split

# Coleta labels
labels = [get_majority_class(f) for f in files]

train, test = train_test_split(files, stratify=labels, test_size=0.3)
```

---

## Recursos Adicionais

### Visualização de Augmentation

```python
import cv2
import matplotlib.pyplot as plt

def visualize_augmentation(image_path, label_path):
    """Visualiza imagem com bounding boxes"""
    img = cv2.imread(image_path)
    h, w = img.shape[:2]
    
    with open(label_path, 'r') as f:
        for line in f:
            cls_id, x, y, width, height = map(float, line.strip().split())
            
            # Desnormaliza
            x1 = int((x - width/2) * w)
            y1 = int((y - height/2) * h)
            x2 = int((x + width/2) * w)
            y2 = int((y + height/2) * h)
            
            # Desenha box
            cv2.rectangle(img, (x1, y1), (x2, y2), (0, 255, 0), 2)
            cv2.putText(img, f"Class {int(cls_id)}", (x1, y1-5),
                       cv2.FONT_HERSHEY_SIMPLEX, 0.5, (0, 255, 0), 2)
    
    plt.imshow(cv2.cvtColor(img, cv2.COLOR_BGR2RGB))
    plt.axis('off')
    plt.show()
```

### Estatísticas do Dataset

```python
def dataset_statistics(labels_dir):
    """Calcula estatísticas do dataset"""
    from collections import Counter
    
    class_counts = Counter()
    box_sizes = []
    
    for label_file in Path(labels_dir).glob('*.txt'):
        with open(label_file, 'r') as f:
            for line in f:
                cls_id, x, y, w, h = map(float, line.strip().split())
                class_counts[int(cls_id)] += 1
                box_sizes.append(w * h)
    
    print("Distribuição de Classes:")
    for cls_id, count in class_counts.items():
        print(f"  Classe {cls_id}: {count} objetos")
    
    print(f"\nTamanho médio de box: {np.mean(box_sizes):.4f}")
    print(f"Tamanho min/max: {min(box_sizes):.4f} / {max(box_sizes):.4f}")
```

---

## Integração com YOLO

### Criar data.yaml

```python
import yaml

data = {
    'path': 'dataset',
    'train': 'images/train',
    'val': 'images/val',
    'test': 'images/test',
    'nc': 2,
    'names': {0: 'cubo', 1: 'esfera'}
}

with open('data.yaml', 'w') as f:
    yaml.dump(data, f, default_flow_style=False)
```

### Usar com Ultralytics

```python
from ultralytics import YOLO

# Treinar
model = YOLO('yolo11s.pt')
model.train(data='data.yaml', epochs=100, imgsz=640)
```

---

## Notas Importantes

- ⚠️ Sempre faça backup antes de remover arquivos HEIC
- ⚠️ Valide labels após cada conversão
- ⚠️ Augmentation pode aumentar dataset em 5-10x
- ⚠️ Use seed fixo para reprodutibilidade
- ⚠️ Monitore espaço em disco durante augmentation

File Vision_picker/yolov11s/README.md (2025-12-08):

# YOLOv11s - Detecção de Objetos em Tempo Real

Sistema de detecção de objetos baseado em YOLOv11 small, especializado na identificação de cubos e esferas.

## Visão Geral

Este módulo implementa um detector de objetos usando a arquitetura YOLOv11s (small), otimizado para identificar formas geométricas (cubos e esferas) em tempo real. O sistema integra download automático de dataset do Roboflow, filtragem de classes, data augmentation e treinamento completo.

## Estrutura

```
yolov11s/
├── train.py                  # Script completo de treinamento
├── inference_yolov11.py      # Script de inferência/detecção
└── runs/                     # Resultados de treinamento
    └── detect/
        └── cubes_spheres_yolo11s/
            ├── weights/
            │   ├── best.pt   # Melhor modelo
            │   └── last.pt   # Último checkpoint
            ├── args.yaml     # Argumentos de treinamento
            ├── results.png   # Gráficos de métricas
            └── confusion_matrix.png
```

## Instalação

### Dependências
```bash
pip install ultralytics>=8.0.0 roboflow opencv-python pyyaml matplotlib seaborn torch torchvision
```

### Verificar GPU
```python
import torch
print(f"CUDA disponível: {torch.cuda.is_available()}")
print(f"Device: {torch.cuda.get_device_name(0) if torch.cuda.is_available() else 'CPU'}")
```

## Funcionamento

### Pipeline de Treinamento (train.py)

```mermaid
graph TD
    A[Download Dataset] --> B[Filtragem de Classes]
    B --> C[Redistribuição Train/Val/Test]
    C --> D[Augmentation de Esferas]
    D --> E[Criação de data.yaml]
    E --> F[Treinamento YOLOv11s]
    F --> G[Validação]
    G --> H[Salvamento de Modelo]
```

#### 1. Download do Dataset (Roboflow)
```python
API_KEY = "RGZ4JUpt6YMS1ZreoZAT"
WORKSPACE = "w0"
PROJECT = "3d-geom-shape-detector"
VERSION = 1

rf = Roboflow(api_key=API_KEY)
project = rf.workspace(WORKSPACE).project(PROJECT)
dataset = project.version(VERSION).download("yolov8")
```

#### 2. Filtragem de Classes
- Mantém apenas classes: **cubo** e **esfera**
- Remove outras formas geométricas (cilindros, pirâmides, etc.)
- Exclui imagens e labels de classes não desejadas

#### 3. Redistribuição do Dataset
```python
TRAIN_PCT = 70   # 70% para treinamento
VAL_PCT = 20     # 20% para validação
TEST_PCT = 10    # 10% para teste
```

#### 4. Data Augmentation (apenas esferas)
Aplicado para equilibrar classes:
```python
augmentations = [
    HorizontalFlip(p=0.5),
    VerticalFlip(p=0.3),
    Rotate(limit=25, p=0.5),
    RandomBrightnessContrast(p=0.5),
    GaussNoise(p=0.3),
    Blur(p=0.3)
]
```

#### 5. Treinamento
```python
model = YOLO('yolo11s.pt')
results = model.train(
    data='data.yaml',
    epochs=150,
    batch=16,
    imgsz=640,
    device='cuda' if torch.cuda.is_available() else 'cpu',
    patience=20,
    save=True,
    plots=True
)
```

## Uso

### Treinar Modelo

```bash
python train.py
```

**Processo automático:**
1. ✅ Download do dataset do Roboflow
2. ✅ Filtragem de classes
3. ✅ Redistribuição 70/20/10
4. ✅ Augmentation de esferas
5. ✅ Criação de data.yaml
6. ✅ Treinamento por 150 épocas
7. ✅ Salvamento de best.pt e last.pt

**Tempo estimado:**
- GPU (RTX 3060): ~2-3 horas
- CPU: ~10-15 horas

### Inferência - Webcam em Tempo Real

```bash
python inference_yolov11.py
```

**Controles:**
- **Espaço**: Pausar/Continuar
- **'s'**: Salvar frame atual
- **'q'**: Sair

### Inferência - Imagem

```python
from ultralytics import YOLO

model = YOLO('runs/detect/cubes_spheres_yolo11s/weights/best.pt')
results = model.predict('image.jpg', conf=0.5)
results[0].show()
```

### Inferência - Vídeo

```python
model = YOLO('runs/detect/cubes_spheres_yolo11s/weights/best.pt')
results = model.predict('video.mp4', save=True, conf=0.5)
```

## Configuração

### Parâmetros de Treinamento (train.py)

```python
# Dataset Roboflow
API_KEY = "RGZ4JUpt6YMS1ZreoZAT"
WORKSPACE = "w0"
PROJECT = "3d-geom-shape-detector"
VERSION = 1

# Divisão do dataset
TRAIN_PCT = 70
VAL_PCT = 20
TEST_PCT = 10

# Diretórios
OUTPUT_DIR = "dataset_balanced"

# Modelo
MODEL = "yolo11s"  # ou "yolo11n", "yolo11m", "yolo11l", "yolo11x"

# Hiperparâmetros
EPOCHS = 150
BATCH_SIZE = 16
IMG_SIZE = 640

# Device
DEVICE = 'cuda' if torch.cuda.is_available() else 'cpu'

# Classes mantidas
KEEP_CLASSES = ['cubo', 'esfera']
```

### Parâmetros de Inferência (inference_yolov11.py)

```python
MODEL_PATH = 'runs/detect/cubes_spheres_yolo11s/weights/best.pt'
CONFIDENCE_THRESHOLD = 0.5
IOU_THRESHOLD = 0.45
DEVICE = 'cuda' if torch.cuda.is_available() else 'cpu'
```

## Métricas e Resultados

### Métricas Calculadas

Durante o treinamento, o YOLO calcula:

- **Precision**: Proporção de detecções corretas
- **Recall**: Proporção de objetos detectados
- **mAP@0.5**: Mean Average Precision com IoU threshold de 0.5
- **mAP@0.5:0.95**: mAP calculado de IoU 0.5 a 0.95

### Resultados Esperados

```
Época 150/150:
├── Box Loss: 0.8 → 0.3
├── Class Loss: 1.2 → 0.4
├── DFL Loss: 1.0 → 0.6
├── Precision: 0.93
├── Recall: 0.92
└── mAP@0.5: 0.95
```

### Visualizações Geradas

O treinamento gera automaticamente:

1. **results.png**: Curvas de loss e métricas
2. **confusion_matrix.png**: Matriz de confusão
3. **PR_curve.png**: Curva Precision-Recall
4. **F1_curve.png**: Curva F1-Score
5. **labels.jpg**: Distribuição de labels
6. **val_batch_predictions.jpg**: Exemplos de predições

## Formato de Saída

### Detecção em Tempo Real

```
Frame: 1234
FPS: 45.2

Detecções:
  - Cubo: 2 objetos
    [1] Conf: 0.94 | Box: (120, 150, 320, 380)
    [2] Conf: 0.89 | Box: (450, 200, 580, 410)
  
  - Esfera: 1 objeto
    [1] Conf: 0.96 | Box: (300, 100, 450, 280)

Total: 3 objetos
```

### Bounding Box

Cada detecção contém:
```python
result.boxes.xyxy     # Coordenadas [x1, y1, x2, y2]
result.boxes.conf     # Confidence score [0-1]
result.boxes.cls      # Classe (0=cubo, 1=esfera)
```

## Arquitetura YOLOv11s

### Componentes Principais

1. **Backbone**: CSPDarknet53
   - Feature extraction em múltiplas escalas
   - Cross-Stage Partial connections

2. **Neck**: PANet (Path Aggregation Network)
   - Fusão de features multi-escala
   - Bottom-up + Top-down paths

3. **Head**: YOLO Detection Head
   - Anchor-free detection
   - Predição de bounding boxes + classes

### Especificações

| Parâmetro | Valor |
|---|---|
| **Tamanho** | ~20-25 MB |
| **Parâmetros** | ~11M |
| **FPS (GPU)** | 30-60 |
| **FPS (CPU)** | 5-10 |
| **Input Size** | 640x640 |
| **Classes** | 2 (cubo, esfera) |

## Casos de Uso

### 1. Detecção em Tempo Real
```python
import cv2
from ultralytics import YOLO

model = YOLO('best.pt')
cap = cv2.VideoCapture(0)

while True:
    ret, frame = cap.read()
    if not ret:
        break
    
    results = model.predict(frame, conf=0.5)
    annotated = results[0].plot()
    
    cv2.imshow('Detection', annotated)
    if cv2.waitKey(1) & 0xFF == ord('q'):
        break

cap.release()
cv2.destroyAllWindows()
```

### 2. Batch Processing
```python
from pathlib import Path

model = YOLO('best.pt')
image_dir = Path('images/')

for img_path in image_dir.glob('*.jpg'):
    results = model.predict(str(img_path), save=True)
    print(f"{img_path.name}: {len(results[0].boxes)} objetos")
```

### 3. Extração de Coordenadas
```python
results = model.predict('image.jpg')

for box in results[0].boxes:
    x1, y1, x2, y2 = box.xyxy[0]
    conf = box.conf[0]
    cls = int(box.cls[0])
    
    center_x = (x1 + x2) / 2
    center_y = (y1 + y2) / 2
    
    print(f"Classe {cls}: Centro ({center_x:.1f}, {center_y:.1f}) | Conf: {conf:.2f}")
```

## Troubleshooting

### Erro: CUDA out of memory
```python
# Reduz batch size
BATCH_SIZE = 8  # ou 4

# Ou força CPU
DEVICE = 'cpu'
```

### Dataset vazio após filtragem
```python
# Verifica classes disponíveis no dataset
import yaml
with open('data.yaml', 'r') as f:
    data = yaml.safe_load(f)
print(f"Classes: {data['names']}")
```

### Modelo não converge
- Aumentar epochs (200-300)
- Ajustar learning rate
- Verificar qualidade das anotações
- Aumentar dataset com augmentation

### FPS baixo
```python
# Usar modelo menor
model = YOLO('yolo11n.pt')  # nano version

# Reduzir tamanho da imagem
results = model.predict(frame, imgsz=320)

# Half precision (GPU)
model = YOLO('best.pt', half=True)
```

## Data Augmentation

### Transformações Aplicadas (apenas esferas)

```python
import albumentations as A

transform = A.Compose([
    A.HorizontalFlip(p=0.5),
    A.VerticalFlip(p=0.3),
    A.Rotate(limit=25, p=0.5),
    A.RandomBrightnessContrast(
        brightness_limit=0.2, 
        contrast_limit=0.2, 
        p=0.5
    ),
    A.GaussNoise(var_limit=(10.0, 50.0), p=0.3),
    A.GaussianBlur(blur_limit=(3, 7), p=0.3),
    A.HueSaturationValue(
        hue_shift_limit=20,
        sat_shift_limit=30,
        val_shift_limit=20,
        p=0.5
    )
], bbox_params=A.BboxParams(
    format='yolo',
    label_fields=['class_labels']
))
```

## Fine-tuning

### Retreinar com Novos Dados

```python
# Carrega modelo pré-treinado
model = YOLO('runs/detect/cubes_spheres_yolo11s/weights/best.pt')

# Continua treinamento
model.train(
    data='new_data.yaml',
    epochs=50,
    batch=16,
    resume=True  # Continua do checkpoint
)
```

### Transfer Learning

```python
# Usa modelo base COCO
model = YOLO('yolo11s.pt')

# Fine-tune para suas classes
model.train(
    data='data.yaml',
    epochs=100,
    freeze=10  # Congela primeiras 10 camadas
)
```

## Recursos Adicionais

### Otimizações Avançadas

1. **TensorRT** (NVIDIA GPU)
```python
model.export(format='engine')  # Converte para TensorRT
```

2. **ONNX** (Cross-platform)
```python
model.export(format='onnx')
```

3. **CoreML** (iOS/macOS)
```python
model.export(format='coreml')
```

### Hyperparameter Tuning

```python
model.tune(
    data='data.yaml',
    epochs=30,
    iterations=300,
    optimizer='AdamW'
)
```

## Formato data.yaml

```yaml
path: dataset_balanced
train: images/train
val: images/val
test: images/test

nc: 2
names:
  0: cubo
  1: esfera
```

## Comparação de Modelos YOLO

| Modelo | Tamanho | Parâmetros | FPS (GPU) | mAP |
|---|---|---|---|-----|
| YOLOv11n | 6 MB | 3M | 80+ | 0.93 |
| **YOLOv11s** | **22 MB** | **11M** | **60** | **0.95** |
| YOLOv11m | 50 MB | 25M | 40 | 0.96 |
| YOLOv11l | 100 MB | 50M | 25 | 0.97 |

## Integração com Sistema

### Integração com Coords
```python
# get_pos.py pode usar este modelo
from ultralytics import YOLO

model = YOLO('yolov11s/runs/detect/cubes_spheres_yolo11s/weights/best.pt')
results = model.predict(frame)

for box in results[0].boxes:
    x1, y1, x2, y2 = box.xyxy[0]
    center = ((x1 + x2) / 2, (y1 + y2) / 2)
    # Enviar coordenadas para controle robótico
```

### Integração com Hardware
```python
# Enviar comandos para ESP32 baseado em detecções
if len(results[0].boxes) > 0:
    # Pegar primeiro objeto
    box = results[0].boxes[0]
    center_x, center_y = calcular_centro(box)
    
    # Enviar coordenadas via serial
    send_to_esp32(center_x, center_y)
```

## Performance Tips

1. **Use GPU**: ~10x mais rápido que CPU
2. **Half Precision**: 2x mais rápido em GPUs compatíveis
3. **Batch Processing**: Mais eficiente que frame-by-frame
4. **Resize Input**: Imagens menores = mais FPS
5. **Model Quantization**: Menor tamanho, mantém precisão

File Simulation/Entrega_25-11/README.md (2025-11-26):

# Sistema de Visão Computacional para Garra Robótica
## Sprint - Migração de Câmera Acoplada para Câmera Externa

### 📋 Resumo do Projeto

Este projeto implementa um sistema de visão computacional para controle de uma garra robótica no CoppeliaSim. Durante esta sprint, foi realizada a migração completa do sistema de câmera acoplada à garra para um sistema com câmera externa posicionada em tripé.

---

## 🔄 Modelo Anterior vs Modelo Atual

### **Modelo Anterior: Câmera Acoplada**
- Câmera montada diretamente na garra
- Sistema de perseguição por pixel simples
- Movimento direto baseado na posição do objeto na imagem
- Menos complexidade matemática
- Campo de visão limitado à área próxima da garra

### **Modelo Atual: Câmera Externa (Tripé)**
- Câmera posicionada em tripé fixo com ângulo de -45°
- Projeção geométrica complexa (raycasting 3D)
- Transformação de coordenadas: Pixel → Mundo → Junta
- Calibração completa dos eixos XY e Z
- Visão ampla de toda a área de trabalho

---

## 🎯 Objetivos Alcançados

### 1. **Calibração do Sistema de Coordenadas**

#### Calibração XY
- Descoberta do mapeamento entre coordenadas do mundo e juntas
- Identificação de inversão do eixo Y
- Cálculo de offsets: X = +0.175m, Y = +0.300m

**Fórmulas Finais:**
```
MundoX = JX × 1.0 + 0.175
MundoY = JY × (-1.0) + 0.300
```

#### Calibração Z
- Descoberta dos limites físicos da junta Z
- Definição de alturas de operação seguras
- Range: -0.250 a +0.350

**Alturas Configuradas:**
- Navegação: 0.15m (altura inicial)
- Descida fina: 0.005m por clique

### 2. **Sistema de Projeção 3D**

Implementação de cálculo matemático completo:
1. Captura de pixel vermelho na imagem (256×256)
2. Normalização de coordenadas de tela
3. Cálculo do vetor de direção da câmera
4. Transformação para sistema de coordenadas mundial
5. Interseção do raio com o plano do objeto (Z = 0.05m)
6. Conversão para coordenadas das juntas

### 3. **Sistema de Trava XY**

Solução para interferência visual quando a garra entra no campo de visão:
- Botão "Iniciar Descida" trava posições X e Y
- Permite descida controlada sem movimentos indesejados
- Destrava automaticamente ao abrir a garra
- Previne oscilações causadas pela detecção da própria garra

### 4. **Controle Fino de Altura**

- Passo reduzido para descida: 0.5cm por clique
- Permite aproximação precisa do objeto
- Evita colisões com o cubo de 10cm de altura

---

## 🛠️ Componentes Técnicos

### Estrutura Física
- **Câmera (VS)**: Posição [0.2125, -0.150, 0.800], ângulo -45°
- **Área de trabalho**: 
  - X: -0.050 a 0.475m (52.5cm)
  - Y: 0.050 a 0.550m (50cm)
  - Z: -0.250 a 0.350m (60cm)
- **Objeto alvo**: Cubo vermelho 10×10×10cm

### Detecção de Cor
Filtro RGB para vermelho:
```lua
R > 130 AND R > G + 50 AND R > B + 50
```

### Parâmetros de Controle
- Tolerância XY: 0.5cm (precisão de posicionamento)
- Passo XY: 2.5cm (ajuste manual lateral)
- Passo Z: 0.5cm (descida granular)

---

## 📐 Algoritmo Principal

```
1. DETECÇÃO
   └─> Identificar pixels vermelhos na imagem da câmera
   └─> Calcular centroide dos pixels detectados

2. PROJEÇÃO 3D
   └─> Converter pixel (px, py) para coordenadas normalizadas
   └─> Aplicar matriz de transformação da câmera
   └─> Calcular interseção do raio com plano Z = 0.05m
   └─> Obter posição (mundoX, mundoY) no mundo real

3. CONVERSÃO DE COORDENADAS
   └─> Aplicar fórmulas de calibração
   └─> Converter (mundoX, mundoY) para (juntaX, juntaY)
   └─> Aplicar limites de segurança

4. CONTROLE DE MOVIMENTO
   └─> Se não travado: seguir objeto em XY
   └─> Se travado: manter XY fixo, permitir apenas Z
   └─> Enviar comandos para as juntas
```

---

## 🎮 Fluxo de Operação

1. **Inicialização**
   - Sistema detecta objeto vermelho
   - Garra segue automaticamente em XY
   - Altura Z em 0.15m (segura)

2. **Posicionamento**
   - Ajustar XY automaticamente (ou manual com setas)
   - Observar linha verde (debug) apontando para o objeto

3. **Descida Controlada**
   - Clicar "INICIAR DESCIDA" (trava XY)
   - Usar Z- para descer em passos de 0.5cm
   - Aproximar da altura do cubo (~0.05-0.10m)

4. **Captura**
   - Clicar "Fechar Garra"
   - Garra captura o objeto

5. **Reset**
   - Clicar "Abrir Garra"
   - Sistema destrava XY automaticamente
   - Volta ao modo de rastreamento normal

---

## 🔧 Scripts Desenvolvidos

### Script Principal
**`script.lua`**
- Sistema completo de visão e controle
- Projeção 3D e conversão de coordenadas
- Interface de controle

## 🚀 Melhorias em Relação ao Modelo Anterior

| Aspecto | Modelo Anterior | Modelo Atual |
|---|---|---|
| **Campo de visão** | Limitado (câmera na garra) | Amplo (câmera externa) |
| **Complexidade** | Baixa (pixel → movimento) | Alta (projeção 3D completa) |
| **Precisão** | Dependente da distância | Calibrada e consistente |
| **Interferência** | Problema na garra | Resolvido com trava XY |
| **Calibração** | Não necessária | Sistema completo |
| **Área de trabalho** | Pequena | Grande (52×50cm) |
| **Manutenibilidade** | Acoplamento físico | Independente da garra |

---

## 📊 Desafios Superados

### 1. **Mapeamento de Coordenadas**
- **Problema**: Coordenadas do mundo não correspondiam diretamente às juntas
- **Solução**: Script de calibração que testou a garra em múltiplas posições
- **Resultado**: Fórmulas exatas de conversão com offset e inversão de Y

### 2. **Inversão do Eixo Y**
- **Problema**: JY aumenta → MundoY diminui (comportamento contra-intuitivo)
- **Solução**: Aplicação de escala negativa (-1.0) na conversão
- **Resultado**: Movimento correto da garra

### 3. **Interferência Visual**
- **Problema**: Garra entra no campo de visão ao descer, causando oscilações
- **Solução**: Sistema de trava manual que congela XY durante descida
- **Resultado**: Descida estável e controlada

### 4. **Projeção 3D Complexa**
- **Problema**: Câmera a 45° requer cálculo geométrico avançado
- **Solução**: Implementação de raycasting com matriz de transformação
- **Resultado**: Detecção precisa da posição 3D do objeto

### 5. **Controle de Altura**
- **Problema**: Passos muito grandes causavam colisões
- **Solução**: Passo reduzido de 2.5cm para 0.5cm em Z
- **Resultado**: Descida precisa sem colisões

---

## 🎓 Conceitos Aplicados

- **Visão Computacional**: Detecção de cor, processamento de imagem
- **Geometria 3D**: Projeção perspectiva, raycasting, interseção raio-plano
- **Álgebra Linear**: Transformações de coordenadas, matrizes de rotação
- **Robótica**: Cinemática, controle de juntas, espaço de trabalho
- **Calibração**: Mapeamento de sistemas de referência, identificação de parâmetros
- **Engenharia de Software**: Máquina de estados, modularização, debugging

---

## 📝 Próximos Passos Sugeridos

1. **Automação Completa**: Sistema que desce automaticamente quando bem posicionado
2. **Múltiplos Objetos**: Detecção e seleção entre vários cubos
3. **Cores Diferentes**: Expandir detecção para outras cores
4. **Feedback de Força**: Detectar quando garra toca o objeto
5. **Machine Learning**: Melhorar detecção com redes neurais (YOLO)
6. **Trajetórias Otimizadas**: Planejamento de caminho mais eficiente

---
Projeto acadêmico desenvolvido para fins educacionais no SENAI.

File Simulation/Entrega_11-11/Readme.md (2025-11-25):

# Projeto FigurePicker - Versão Prévia (11/11/2025)

> **Nota:** Esta é uma versão anterior do projeto, especificamente a entrega realizada em **11 de novembro de 2025**. 

---

## Execução da Simulação (Vídeo)

Visualização do comportamento dinâmico do manipulador e resposta do controle visual.

Demonstração da Simulação

---

##  1. Camada Física e Cinemática

A simulação modela um robô de topologia cartesiana (PPP - Prismático, Prismático, Prismático), operando em um espaço de trabalho tridimensional limitado.

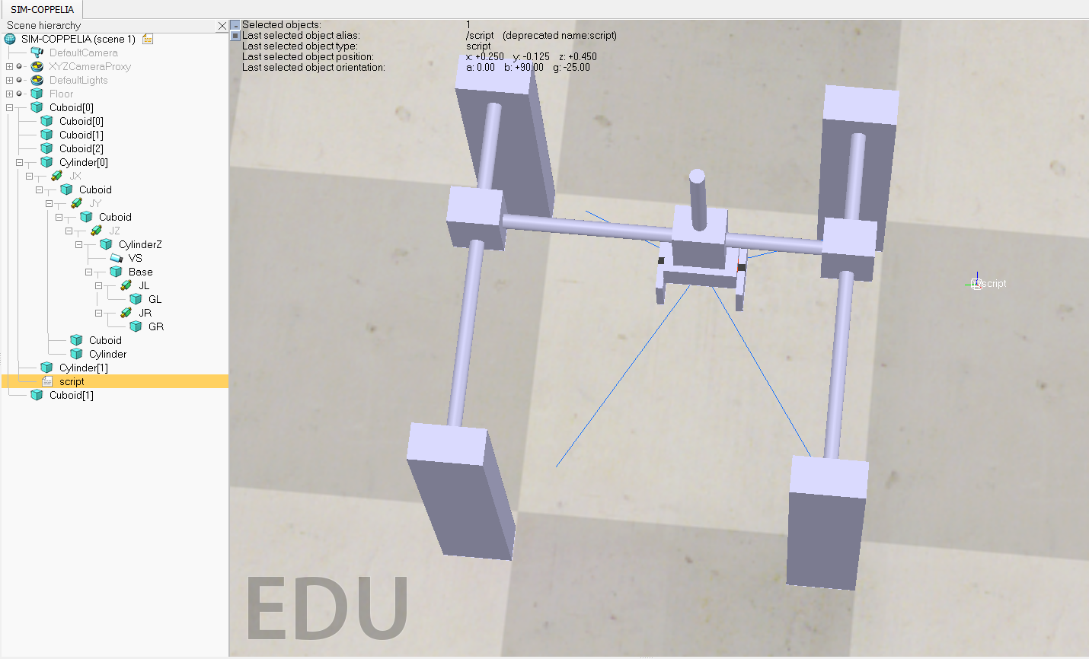
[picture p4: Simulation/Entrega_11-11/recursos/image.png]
Projeto e Hierarquia


### Topologia das Juntas
* **Atuadores:** 3 Juntas Prismáticas (`/JX`, `/JY`, `/JZ`) ortogonais entre si.
* **Efetuador Final:** Garra de acionamento paralelo composta por duas juntas deslizantes (`/JL`, `/JR`) que operam em simetria oposta.
* **Modo de Controle:** As juntas operam em *Position Control* (Malha fechada de posição), onde o motor aplica força até atingir a coordenada alvo (`sim.setJointTargetPosition`).

### Restrições Espaciais (Hard Limits)
Para garantir a integridade da simulação, foram implementados limites de software que restringem o volume de trabalho ($\mathbb{R}^3$):

| Eixo | Mínimo (m) | Máximo (m) | Resolução de Passo |
| :--- | :--- | :--- | :--- |
| **X** | -0.175 | 0.250 | 0.025 |
| **Y** | -0.200 | 0.200 | 0.025 |
| **Z** | -0.240 | 0.050 | Variável |

---

##  2. Lógica de Controle (Script)

O controle é centralizado em um único *Threaded Script* (Lua) que gerencia a máquina de estados do robô.

### Fluxo de Execução
1.  **Inicialização (`sysCall_init`):** Mapeamento dos *handles* dos objetos, ativação dos drivers de motor e renderização da GUI XML.
2.  **Loop de Sensoriamento (`sysCall_sensing`):**
    * Captura o buffer de imagem do sensor.
    * Executa o algoritmo de segmentação de cor.
    * Calcula o vetor de erro (diferença entre o centro da imagem e o centro do objeto).
3.  **Loop de Atuação (Event-Driven):**
    * A atualização de posição ocorre via *interrupções de UI* (cliques manuais) ou via *correção automática* (quando o sensor detecta o alvo).
    * A função `moverGarra()` atua como despachante final, enviando os valores de `alvoX`, `alvoY` e `alvoZ` para a API do simulador.

!

---

##  3. Sistema de Visão e Processamento

A simulação utiliza um sensor de visão RGB (`/VS`) acoplado ao efetuador (Eye-in-Hand configuration) para realizar o rastreamento ativo.

### Algoritmo de Detecção
O processamento de imagem é realizado pixel-a-pixel no array bruto da câmera:

1.  **Thresholding (Limiarização):** Filtra pixels que satisfazem a condição lógica:
    $$Pixel_{vermelho} \iff (R > 150) \land (G < 80) \land (B < 80)$$
2.  **Cálculo de Centroide:** Realiza a média aritmética das coordenadas $(x, y)$ de todos os pixels ativos para encontrar o centro de massa do objeto.
3.  **Feedback de Posição:**
    O erro de posição é realimentado no sistema de controle para ajustar as coordenadas $X$ e $Y$ do robô proporcionalmente ao desvio detectado:
    ```lua
    alvoX = alvoX + (deltaX * ganho)
    alvoY = alvoY - (deltaY * ganho)
    ```

---

##  4. Interface Homem-Máquina (IHM)

A simulação integra uma IHM nativa (`simUI`) que sobrepõe a viewport 3D.

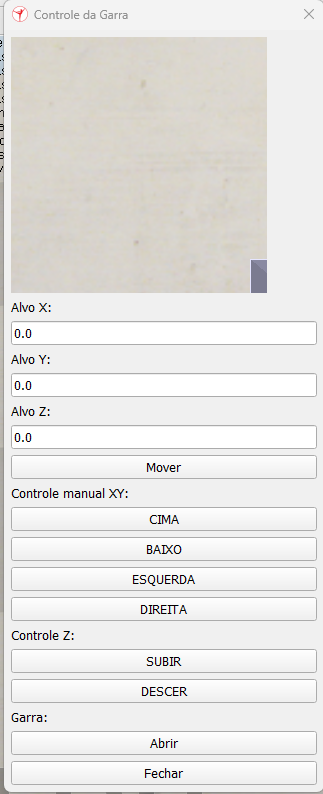
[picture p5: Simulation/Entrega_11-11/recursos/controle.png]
Interface de Controle


* **Visualização:** Renderiza o buffer da câmera do robô em tempo real (`simUI.setImageData`).
* **Telemetria:** Exibe as coordenadas numéricas atuais dos alvos.
* **Intervenção:** Permite override manual das coordenadas calculadas pela visão.

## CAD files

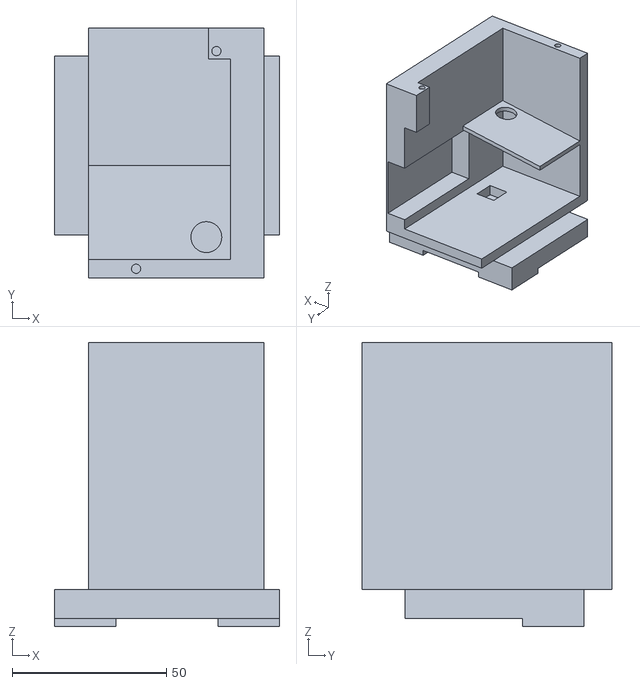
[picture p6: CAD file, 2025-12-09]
Modelos 3D/Base Suspensa Esquerda Fixavel.stl
73.0 x 81.0 x 92.0

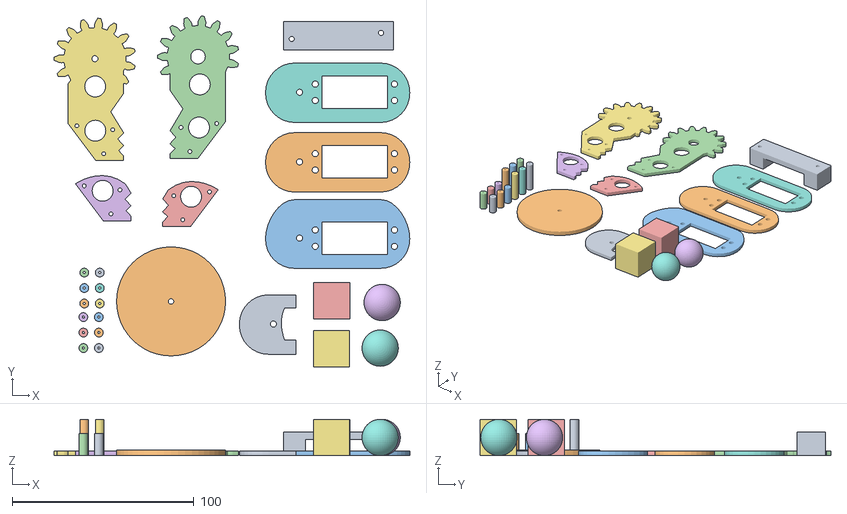
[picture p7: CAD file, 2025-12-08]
Modelos 3D/Garra/tinker.obj
195.7 x 193.2 x 20.0
obj_0
obj_1
obj_2
obj_3
obj_4
obj_5
obj_6
obj_7
obj_8
obj_9
obj_10
obj_11
obj_12
obj_13
obj_14
obj_15
obj_16
obj_17
obj_18
obj_19
obj_20
obj_21
obj_22
obj_23
obj_24
obj_25

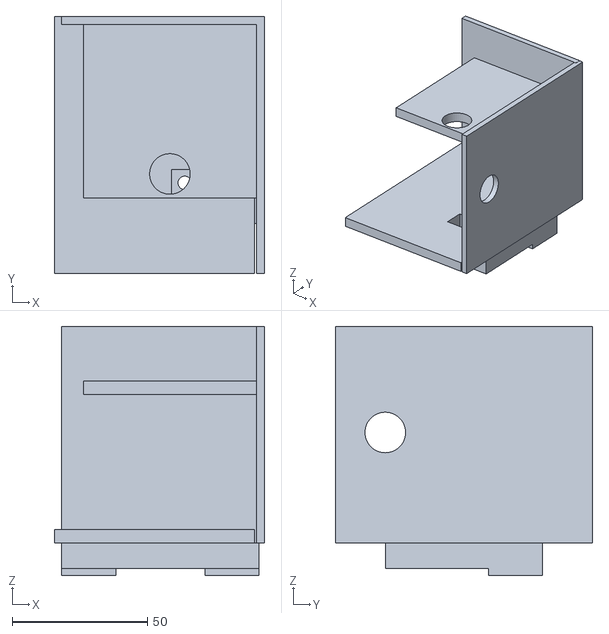
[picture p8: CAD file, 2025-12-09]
Modelos 3D/Base Suspensa Eixo Y Fixavel.stl
77.7 x 95.0 x 92.1

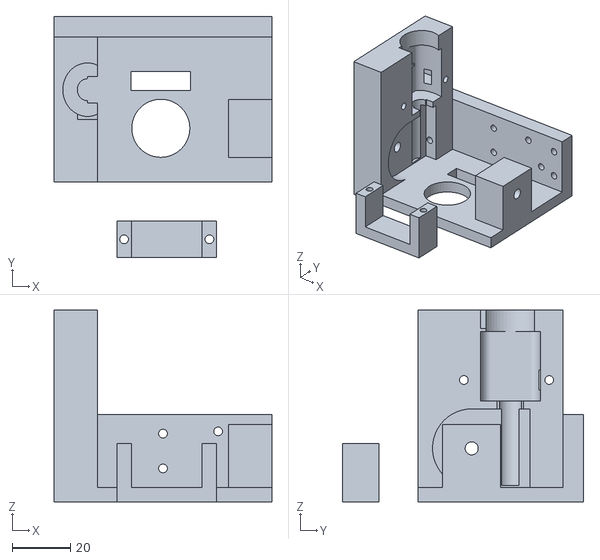
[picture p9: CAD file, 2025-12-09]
Modelos 3D/Suporte Motor Garra.stl
75.0 x 83.0 x 66.0

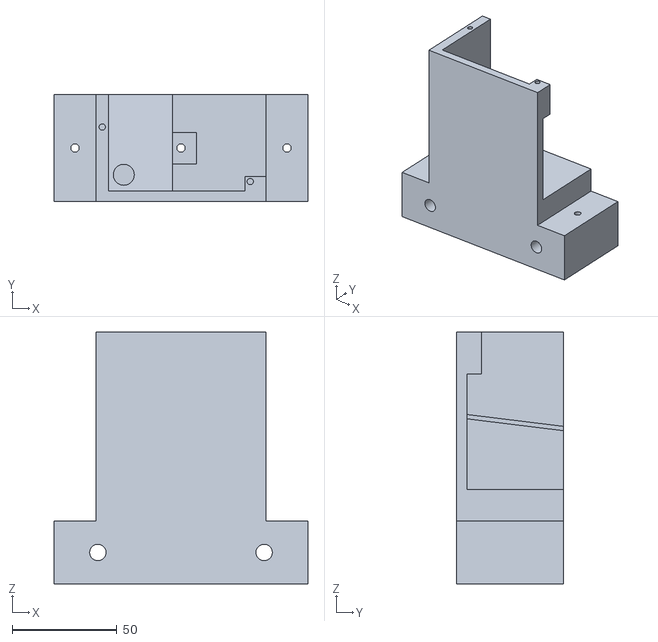
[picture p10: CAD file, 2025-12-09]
Modelos 3D/Base Chão Esquerda Elevada.stl
121.0 x 51.0 x 120.0

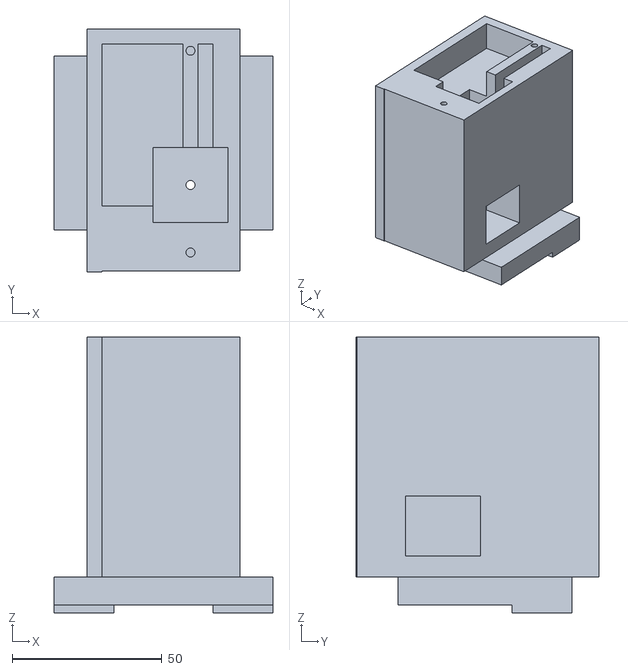
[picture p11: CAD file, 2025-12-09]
Modelos 3D/Base Suspensa Direita Fixavel.stl
73.0 x 81.0 x 92.0

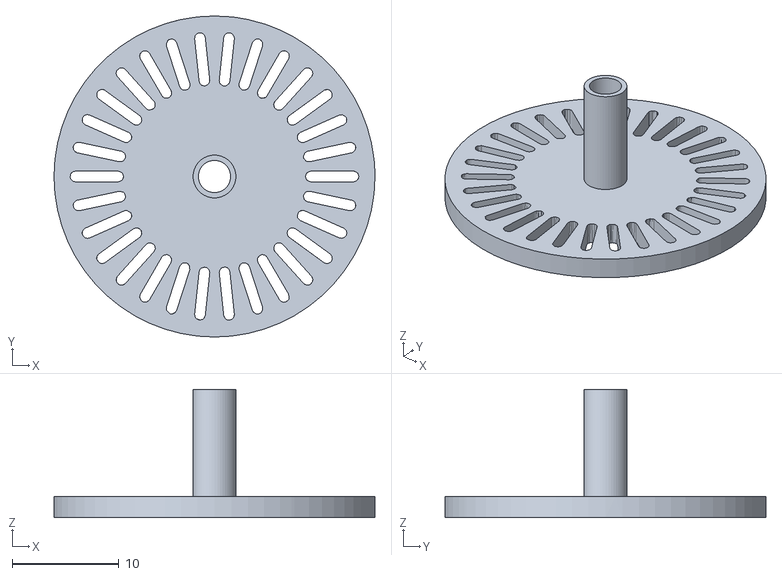
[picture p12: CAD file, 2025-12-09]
Modelos 3D/Rodinha Vazada.stl
30.0 x 30.0 x 12.0

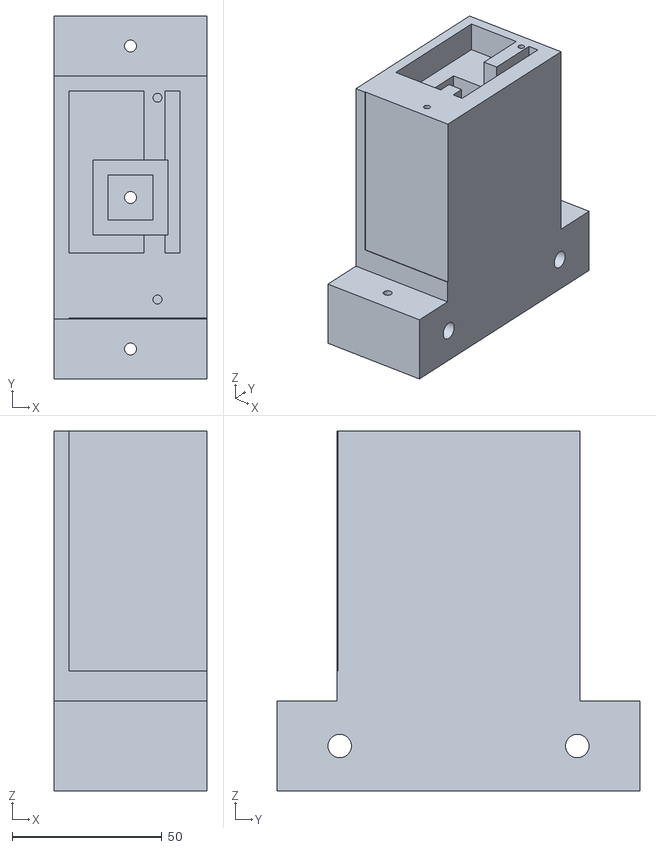
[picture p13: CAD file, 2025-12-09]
Modelos 3D/Base Chão Direita Elevada.stl
51.0 x 121.0 x 120.0

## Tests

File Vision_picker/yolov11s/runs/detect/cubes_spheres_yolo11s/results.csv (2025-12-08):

epoch | time | train/box_loss | train/cls_loss | train/dfl_loss | metrics/precision(B) | metrics/recall(B) | metrics/mAP50(B) | metrics/mAP50-95(B) | val/box_loss | val/cls_loss | val/dfl_loss | lr/pg0 | lr/pg1 | lr/pg2
1 | 44.6682 | 1.27225 | 2.39858 | 1.54318 | 0.89087 | 0.54536 | 0.61492 | 0.4347 | 1.10318 | 1.68761 | 1.39002 | 0.000550165 | 0.000550165 | 0.000550165
2 | 68.7891 | 1.20888 | 0.90389 | 1.43712 | 0.44085 | 0.68966 | 0.51776 | 0.3463 | 1.2141 | 1.73661 | 1.529 | 0.00109853 | 0.00109853 | 0.00109853
3 | 89.9597 | 1.20605 | 0.899 | 1.42118 | 0.78992 | 0.53821 | 0.55149 | 0.38895 | nan | nan | nan | 0.00163957 | 0.00163957 | 0.00163957
4 | 111.409 | 1.18001 | 0.78596 | 1.40578 | 0.79617 | 0.74268 | 0.91574 | 0.61805 | 1.13991 | 1.85474 | 1.32245 | 0.00163399 | 0.00163399 | 0.00163399
5 | 132.965 | 1.18589 | 0.80117 | 1.40482 | 0.79089 | 0.95012 | 0.86602 | 0.5607 | 1.18117 | 0.78792 | 1.34201 | 0.00162299 | 0.00162299 | 0.00162299
6 | 154.467 | 1.14497 | 0.76006 | 1.36924 | 0.95394 | 0.92512 | 0.9564 | 0.64744 | 1.20237 | 0.71775 | 1.36072 | 0.00161199 | 0.00161199 | 0.00161199
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

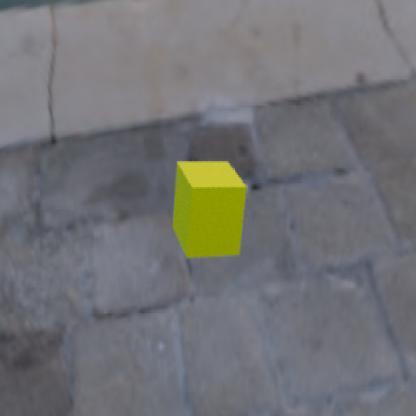
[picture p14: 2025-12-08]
Vision_picker/yolov11s/dataset_balanced/test/images/yellow_cube381_png_jpg.rf.f8e9db440a7e19021ec27c27fefccb19.jpg

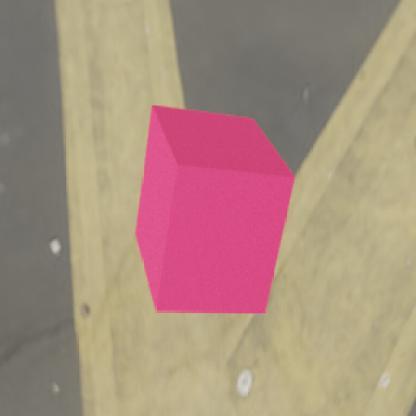
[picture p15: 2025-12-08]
Vision_picker/yolov11s/dataset_balanced/test/images/red_cube396_png_jpg.rf.64648e16445a047cd96e2119c5446e18.jpg

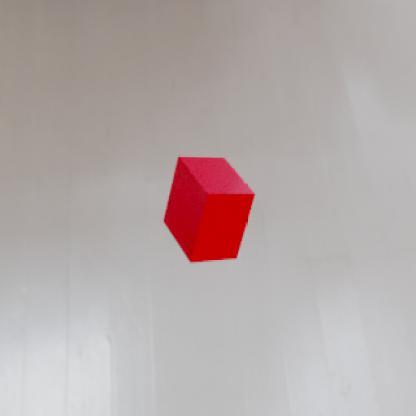
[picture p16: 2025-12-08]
Vision_picker/yolov11s/dataset_balanced/test/images/red_cube327_png_jpg.rf.f00e54e8015ad0ee32e4279e4d800d1b.jpg

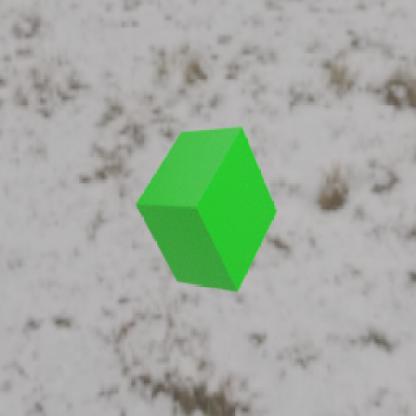
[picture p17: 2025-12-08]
Vision_picker/yolov11s/dataset_balanced/test/images/green_cube189_png_jpg.rf.282a76aa8ed95d713947e20613a8493c.jpg

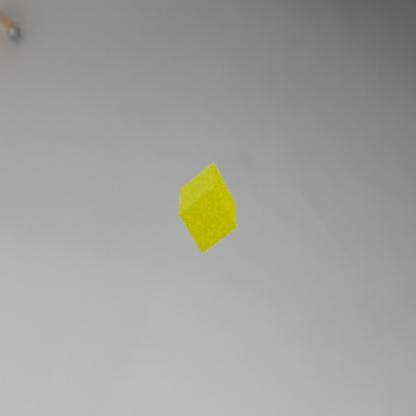
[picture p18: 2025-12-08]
Vision_picker/yolov11s/dataset_balanced/test/images/yellow_cube126_png_jpg.rf.3604c4df8c5c10ae231e97b028bf53e3.jpg

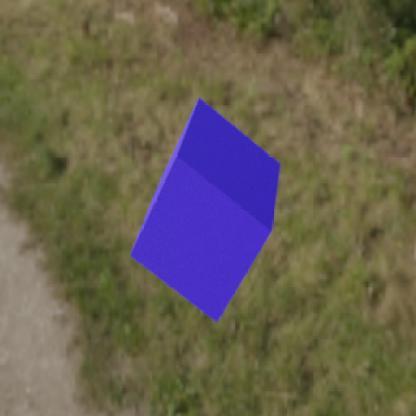
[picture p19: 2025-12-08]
Vision_picker/yolov11s/dataset_balanced/test/images/blue_cube117_png_jpg.rf.2100d22870206acde5283da49ff1d917.jpg

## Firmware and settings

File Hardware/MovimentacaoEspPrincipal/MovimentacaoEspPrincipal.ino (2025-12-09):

#include <Arduino.h>
#include <WiFi.h>
#include <esp_now.h>
#include <esp_wifi.h>

// CONFIGURAÇÃO ESP-NOW
uint8_t broadcastAddress[] = {0xA0, 0xDD, 0x6C, 0x03, 0xE7, 0xB8};

// Estrutura para comunicação ESP-NOW
typedef struct struct_message {
    char command[10];
    long value;
    long position;
} struct_message;

struct_message myData;
struct_message receivedData;

// Variável para controle de delay entre comandos
unsigned long lastCommandTime = 0;
const unsigned long COMMAND_DELAY = 10000;
bool waitingForDelay = false;

// Estruturas para processamento de coordenadas
struct Coordinate {
    float x;
    float y;
};

const int MAX_COORDS = 20;
Coordinate circles[MAX_COORDS];
Coordinate squares[MAX_COORDS];
int circleCount = 0;
int squareCount = 0;

// Estado da sequência automática
enum SequenceState {
    IDLE,
    MOVING_TO_X,
    WAITING_ESP2_PICKUP,
    MOVING_DROP_X_AFTER_PICKUP,
    MOVING_Y_TO_DROP,
    WAITING_DROP,
    RESETTING_AXES,
    SEQUENCE_COMPLETE
};

SequenceState currentState = IDLE;
int currentIndex = 0;
bool processingCircles = true;
unsigned long stateStartTime = 0;
bool sequenceActive = false;

// Conversões
const float PULSES_PER_CM_X = 17.40;
const float PULSES_PER_CM_Y = 18.5;
const long X_BOARD_OFFSET = 110;
const unsigned long ESP2_Y_ARRIVE_TIME = 3000;
const unsigned long ESP2_PICKUP_DOWN_TIME = 5000;
const unsigned long ESP2_PICKUP_TIME = 7000;
const unsigned long ESP2_CLAW_TIME = 2000;
int currentPickUpPoint= 0;

// Prototypes
void OnDataSent(const wifi_tx_info_t *tx_info, esp_now_send_status_t status);
void OnDataRecv(const esp_now_recv_info_t *recv_info, const uint8_t *incomingData, int len);
void IRAM_ATTR handleEncoderA();
void updateEncoder(struct EncoderData &encoder);
void handleButtons();
void handleSerialCommands();
void printHelp();
void printStatus();
void moveToPositionX(long position);
void stopAllMotors();
void stopMotorsX();
void moveBack();
void moveFront();
void resetX();
void printMovement(String movement);
void sendCommandToSecondary(String cmd, long value = 0, long position = 0);
void printEncoderStatus();
void resetAllEncoders();
void updateMotorDirections(int dirA, int dirB);
bool canSendCommand();
void parseCoordinates(String input);
void startSequence();
void processSequence();
long cmToPulsesX(float cm);
long cmToPulsesY(float cm);

// Definições dos pinos de direção - (EIXO X - FREMTE/TRÁS)
#define IN1 32   // Motor A - Sentido 1
#define IN2 33   // Motor A - Sentido 2
#define IN3 12   // Motor B - Sentido 1
#define IN4 13   // Motor B - Sentido 2

// Definições dos botões
#define front 21
#define back 18
#define front_2 5
#define back_2 19
#define stop 27

#define ENCODER_A 34  // Encoder Motor A - Eixo X

// Variáveis de controle de posição
long targetPositionX = 0;
bool movingToTargetX = false;
bool resettingX = false;
bool flopFlopping = false;
String lastCommand = "STOP";
String lastPrintedCommand = "";

int motorDirectionA = 0;
int motorDirectionB = 0;

// Estrutura para armazenar dados dos encoders
struct EncoderData {
  volatile long contador;
  volatile int estadoAnterior;
  volatile boolean contadorAtualizado;
  volatile char direcao;
  volatile unsigned long ultimoTempoInterrupcao;
  int pino;
  int* motorDirection;
};

EncoderData encoderA = {0, 0, false, ' ', 0, ENCODER_A, &motorDirectionA};

const unsigned long DEBOUNCE_TIME = 1;
unsigned long lastButtonTime = 0;
const unsigned long BUTTON_DEBOUNCE = 10;

bool buttonWasPressed = false;
String currentMovement = "";

// CALLBACKS ESP-NOW
void OnDataSent(const wifi_tx_info_t *tx_info, esp_now_send_status_t status) {
    Serial.print("Status do envio: ");
    Serial.println(status == ESP_NOW_SEND_SUCCESS ? "Sucesso" : "Falha");
    waitingForDelay = false;
}

void OnDataRecv(const esp_now_recv_info_t *recv_info, const uint8_t *incomingData, int len) {
    if (len < (int)sizeof(receivedData)) {
        Serial.println("Tamanho de dados recebido inválido");
        return;
    }
    memcpy(&receivedData, incomingData, sizeof(receivedData));
    Serial.print("Confirmação recebida: ");
    Serial.print(receivedData.command);
    Serial.print(" - Valor: ");
    Serial.println(receivedData.value);
}

void setup() {
    Serial.begin(115200);
    delay(100);

    // Configuração de pinos
    pinMode(front, INPUT_PULLUP);
    pinMode(back, INPUT_PULLUP);
    pinMode(front_2, INPUT_PULLUP);
    pinMode(back_2, INPUT_PULLUP);
    pinMode(stop, INPUT_PULLUP);
    pinMode(IN1, OUTPUT);
    pinMode(IN2, OUTPUT);
    pinMode(IN3, OUTPUT);
    pinMode(IN4, OUTPUT);
    pinMode(ENCODER_A, INPUT_PULLUP);

    encoderA.estadoAnterior = digitalRead(ENCODER_A);
    attachInterrupt(digitalPinToInterrupt(ENCODER_A), handleEncoderA, CHANGE);

    // Configuração WiFi e ESP-NOW
    WiFi.mode(WIFI_STA);
    
    if (esp_now_init() != ESP_OK) {
        Serial.println("Erro ao inicializar ESP-NOW");
        return;
    }
    
    // Registrar callbacks
    esp_now_register_send_cb(OnDataSent);
    esp_now_register_recv_cb(OnDataRecv);
    
    // Registrar peer
    esp_now_peer_info_t peerInfo = {};
    memcpy(peerInfo.peer_addr, broadcastAddress, 6);
    peerInfo.channel = 0;
    peerInfo.encrypt = false;
    
    if (esp_now_add_peer(&peerInfo) != ESP_OK) {
        Serial.println("Falha ao adicionar peer");
    }

    stopAllMotors();

    Serial.println("=== ESP PRINCIPAL - EIXO X ===");
    Serial.print("Endereço MAC: ");
    Serial.println(WiFi.macAddress());
    printHelp();
}

void loop() {
  handleButtons();
  handleSerialCommands();

  if (sequenceActive) {
        processSequence();
    }

    // Verifica movimento para posição X
    if (movingToTargetX && !sequenceActive) {
        if (abs(encoderA.contador - targetPositionX) <= 3) {
            stopMotorsX();
            movingToTargetX = false;
            Serial.print("EIXO X chegou na posição: ");
            Serial.println(targetPositionX);
        }
    }

    // Verifica reset X
    if (resettingX && !sequenceActive) {
        if (digitalRead(back) == LOW && digitalRead(back_2) == LOW) {
            stopMotorsX();
            resettingX = false;
            noInterrupts();
            resetAllEncoders();
            interrupts();
            Serial.println("EIXO X resetado - Posição definida como 0");
        }
    }

    delay(10);
}

// Converte cm para pulsos X
long cmToPulsesX(float cm) {
    return (long)(cm * PULSES_PER_CM_X);
}

// Converte cm para pulsos Y
long cmToPulsesY(float cm) {
    return (long)(cm * PULSES_PER_CM_Y);
}

// Processa a sequência automática
void processSequence() {
    unsigned long currentTime = millis();
    
    switch (currentState) {
        case IDLE:
            break;
            
        case MOVING_TO_X: {
            if (abs(encoderA.contador - targetPositionX) <= 3) {
                stopMotorsX();
                Serial.println("Chegou na posição X. Enviando coordenada Y para ESP2");
                Coordinate* currentCoords = processingCircles ? circles : squares;
                long yPulses = cmToPulsesY(currentCoords[currentIndex].y);
                
                sendCommandToSecondary("GOTO_Y", 0, yPulses);                
                currentState = WAITING_ESP2_PICKUP;
                currentPickUpPoint = 0;
                stateStartTime = currentTime;
                Serial.println("Aguardando ESP2 realizar pickup");
            }
            break;
        }
        
        case WAITING_ESP2_PICKUP:
            if ((currentTime - stateStartTime >= ESP2_Y_ARRIVE_TIME) && currentPickUpPoint == 0) {
                Serial.println("Abrindo a garra");
                sendCommandToSecondary("GRIP", 130);
                currentPickUpPoint++;
                stateStartTime = currentTime;
            }

            if ((currentTime - stateStartTime >= ESP2_CLAW_TIME) && currentPickUpPoint == 1) {
                Serial.println("Descendo a garra");
                sendCommandToSecondary("MOVE_Z", -1);
                currentPickUpPoint++;
                stateStartTime = currentTime;
            }

            if ((currentTime - stateStartTime >= ESP2_PICKUP_DOWN_TIME) && currentPickUpPoint == 2) {
                Serial.println("Fechando a garra");
                sendCommandToSecondary("GRIP", 88);
                currentPickUpPoint++;
                stateStartTime = currentTime;
            }

            if ((currentTime - stateStartTime >= ESP2_CLAW_TIME) && currentPickUpPoint == 3) {
                Serial.println("Subindo a garra");
                sendCommandToSecondary("MOVE_Z", 1);
                currentPickUpPoint++;
                stateStartTime = currentTime;
            }
            
            if ((currentTime - stateStartTime >= ESP2_PICKUP_TIME) && currentPickUpPoint == 4) {
                Serial.println("Pickup completo. Indo para a area de drop");
                moveFront();
                currentState = MOVING_DROP_X_AFTER_PICKUP;
            }
            break;
            
        case MOVING_DROP_X_AFTER_PICKUP:
            if (digitalRead(front) == LOW && digitalRead(front_2) == LOW) {
                stopMotorsX();
                noInterrupts();
                encoderA.contador = 0;
                interrupts();
                Serial.println("X na área de drop. Movendo Y para posição de drop...");

                if (processingCircles) {
                    sendCommandToSecondary("MOVE_Y", 1);
                    Serial.println("Movendo para DROP (círculo)");
                } else {
                    sendCommandToSecondary("MOVE_Y", -1);
                    Serial.println("Movendo para DROP (quadrado)");
                }
                
                currentState = MOVING_Y_TO_DROP;
                stateStartTime = currentTime;
            }
            break;
            
        case MOVING_Y_TO_DROP:
            if (currentTime - stateStartTime >= ESP2_Y_ARRIVE_TIME) {
                Serial.println("Y chegou na posição. Abrindo garra...");
                sendCommandToSecondary("GRIP", 110, 0);
                currentState = WAITING_DROP;
                stateStartTime = currentTime;
            }
            break;
            
        case WAITING_DROP:
            if (currentTime - stateStartTime >= ESP2_CLAW_TIME) {
                Serial.println("Drop completo. Fechando garra e resetando eixos...");
                sendCommandToSecondary("GRIP", 88, 0);
                delay(500);
                sendCommandToSecondary("RESET_Y", 0, 0);
                resetX();
                currentState = RESETTING_AXES;
                stateStartTime = currentTime;
            }
            break;
            
        case RESETTING_AXES:
            if (digitalRead(back) == LOW && digitalRead(back_2) == LOW) {
                stopMotorsX();
                resetAllEncoders();
                sendCommandToSecondary("RESET_ENC", 0);
                
                currentIndex++;

                Coordinate* currentCoords = processingCircles ? circles : squares;
                int currentCount = processingCircles ? circleCount : squareCount;
                
                if (currentIndex < currentCount) {
                    Serial.print("Próxima coordenada: ");
                    Serial.print(currentIndex + 1);
                    Serial.print("/");
                    Serial.println(currentCount);
                    
                    long xTarget = cmToPulsesX(currentCoords[currentIndex].x) + X_BOARD_OFFSET;
                    moveToPositionX(xTarget);
                    currentState = MOVING_TO_X;
                } else if (processingCircles && squareCount > 0) {
                    
                    Serial.println("=== CÍRCULOS COMPLETOS. INICIANDO QUADRADOS ===");
                    processingCircles = false;
                    currentIndex = 0;
                    
                    long xTarget = cmToPulsesX(squares[0].x) + X_BOARD_OFFSET;
                    moveToPositionX(xTarget);
                    currentState = MOVING_TO_X;
                } else {
                    currentState = SEQUENCE_COMPLETE;
                    Serial.println("=== SEQUÊNCIA COMPLETA ===");
                    sequenceActive = false;
                }
            }
            break;
            
        case SEQUENCE_COMPLETE:
            sequenceActive = false;
            currentState = IDLE;
            break;
    }
}

// Inicia a sequência automática
void startSequence() {
    if (circleCount == 0 && squareCount == 0) {
        Serial.println("ERRO: Nenhuma coordenada cadastrada!");
        return;
    }
    
    Serial.println("=== INICIANDO SEQUÊNCIA AUTOMÁTICA ===");
    Serial.print("Círculos: ");
    Serial.println(circleCount);
    Serial.print("Quadrados: ");
    Serial.println(squareCount);
    
    Serial.println("Resetando eixos...");
    resetX();
    sendCommandToSecondary("RESET_Y", 0, 0);
    delay(5000);
    
    resetAllEncoders();
    sendCommandToSecondary("RESET_ENC", 0);
    
    processingCircles = (circleCount > 0);
    currentIndex = 0;
    sequenceActive = true;
    
    Coordinate* firstCoords = processingCircles ? circles : squares;
    long xTarget = cmToPulsesX(firstCoords[0].x) + X_BOARD_OFFSET;
    
    Serial.print("Movendo para primeira posição X: ");
    Serial.print(firstCoords[0].x);
    Serial.println(" cm");
    
    moveToPositionX(xTarget);
    currentState = MOVING_TO_X;
}

// Parse coordenadas do formato c[[x1,y1],[x2,y2],...] ou q[[x1,y1],[x2,y2],...]
void parseCoordinates(String input) {
    input.trim();
    
    bool isCircle = (input.charAt(0) == 'c' || input.charAt(0) == 'C');
    bool isSquare = (input.charAt(0) == 'q' || input.charAt(0) == 'Q');
    
    if (!isCircle && !isSquare) {
        Serial.println("ERRO: Formato inválido. Use c[...] ou q[...]");
        return;
    }
    
    input = input.substring(1);
    input.trim();
    
    int count = 0;
    Coordinate* coords = isCircle ? circles : squares;
    
    if (isCircle) {
        circleCount = 0;
    } else {
        squareCount = 0;
    }
    
    int startIdx = 0;
    int depth = 0;
    String currentNumber = "";
    float currentX = 0, currentY = 0;
    bool readingX = true;
    
    for (unsigned int i = 0; i < input.length() && count < MAX_COORDS; i++) {
        char c = input.charAt(i);
        
        switch (c) {
            case '[':
                depth++;
                if (depth == 2) {
                    currentNumber = "";
                    currentX = 0;
                    currentY = 0;
                    readingX = true;
                }
                break;
                
            case ']':
                if (depth == 2) {
                    
                    if (currentNumber.length() > 0) {
                        currentY = currentNumber.toFloat();
                        currentNumber = "";
                    }
                    
                    coords[count].x = currentX;
                    coords[count].y = currentY;
                    count++;
                }
                depth--;
                break;
                
            case ',':
                if (depth == 2) {
                    if (readingX) {
                        currentX = currentNumber.toFloat();
                        currentNumber = "";
                        readingX = false;
                    }
                }
                break;
                
            case ' ':
            case '\t':
            
                break;
                
            default:
                if (depth == 2 && (isdigit(c) || c == '.' || c == '-')) {
                    currentNumber += c;
                }
                break;
        }
    }
    
    if (isCircle) {
        circleCount = count;
        Serial.print("Círculos cadastrados: ");
        Serial.println(circleCount);
        for (int i = 0; i < circleCount; i++) {
            Serial.print("  [");
            Serial.print(circles[i].x);
            Serial.print(", ");
            Serial.print(circles[i].y);
            Serial.println("]");
        }
    } else {
        squareCount = count;
        Serial.print("Quadrados cadastrados: ");
        Serial.println(squareCount);
        for (int i = 0; i < squareCount; i++) {
            Serial.print("  [");
            Serial.print(squares[i].x);
            Serial.print(", ");
            Serial.print(squares[i].y);
            Serial.println("]");
        }
    }
}

// Verifica se pode enviar comando
bool canSendCommand() {
    if (waitingForDelay) {
        unsigned long currentTime = millis();
        if (currentTime - lastCommandTime < COMMAND_DELAY) {
            Serial.print("Aguarde ");
            Serial.print((COMMAND_DELAY - (currentTime - lastCommandTime)) / 1000);
            Serial.println(" segundos antes do próximo comando");
            return false;
        }
        waitingForDelay = false;
    }
    return true;
}

// Comunicação com a ESP Secundária
void sendCommandToSecondary(String cmd, long value, long position) {
    if (!canSendCommand()) {
        return;
    }
    
    memset(&myData, 0, sizeof(myData));
    strncpy(myData.command, cmd.c_str(), sizeof(myData.command)-1);
    myData.value = value;
    myData.position = position;
    
    esp_err_t ret = esp_now_send(broadcastAddress, (uint8_t *) &myData, sizeof(myData));
    if(ret != ESP_OK){
        Serial.print("esp_now_send falhou: ");
        Serial.println(ret);
        waitingForDelay = false;
    } else {
        lastCommandTime = millis();
        waitingForDelay = true;
        Serial.println("Comando enviado - Aguardando 10 segundos para próximo");
    }
}


// Função para mover eixo X para posição específica
void moveToPositionX(long position) {
    targetPositionX = position;
    long currentPosition = encoderA.contador;

    if (currentPosition < position) {
        moveFront();
        movingToTargetX = true;
        Serial.print("Movendo EIXO X para FRENTE - Alvo: ");
        Serial.println(position);
    } else if (currentPosition > position) {
        moveBack();
        movingToTargetX = true;
        Serial.print("Movendo EIXO X para TRÁS - Alvo: ");
        Serial.println(position);
    } else {
        stopMotorsX();
        Serial.println("EIXO X já está na posição");
    }
}

// Função para reset do eixo X
void resetX() {
    Serial.println("Iniciando reset EIXO X");
    resettingX = true;
    moveBack();
}

// Função para controle de print de movimento
void printMovement(String movement) {
    if (movement != lastPrintedCommand) {
        Serial.println(movement);
        lastPrintedCommand = movement;
    }
}

// Função para controle dos botões
void handleButtons() {
    if (millis() - lastButtonTime < BUTTON_DEBOUNCE) return;
    if (sequenceActive) return;

    bool frontPressed = (digitalRead(front) == LOW && digitalRead(front_2) == LOW);
    bool backPressed = (digitalRead(back) == LOW && digitalRead(back_2) == LOW);
    bool stopPressed = (digitalRead(stop) == LOW);
    
    bool anyButtonPressed = frontPressed || backPressed || stopPressed;

    if (!anyButtonPressed) {
        buttonWasPressed = false;
        currentMovement = "";
        lastPrintedCommand = "";
        return;
    }

    if(stopPressed){
        if (!buttonWasPressed || currentMovement != "STOP") {
            printMovement("PARANDO TODOS OS MOTORES");
            stopAllMotors();
            movingToTargetX = false;
            resettingX = false;
            sequenceActive = false;
            lastCommand = "STOP";
            currentMovement = "STOP";
            buttonWasPressed = true;
        }
        lastButtonTime = millis();
    }
    else if(frontPressed){
        if (!buttonWasPressed || currentMovement != "FRONT") {
          printEncoderStatus();
          moveFront();
          printMovement("MOVENDO EIXO X: FRENTE");
          movingToTargetX = false;
          lastCommand = "FRONT";
          currentMovement = "FRONT";
          buttonWasPressed = true;
        }
        lastButtonTime = millis();
    }
    else if(backPressed){
        if (!buttonWasPressed || currentMovement != "BACK") {
          printEncoderStatus();
          moveBack();
          printMovement("MOVENDO EIXO X: BACK");
          movingToTargetX = false;
          lastCommand = "BACK";
          currentMovement = "BACK";
          buttonWasPressed = true;
        }
        lastButtonTime = millis();
    }
}
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

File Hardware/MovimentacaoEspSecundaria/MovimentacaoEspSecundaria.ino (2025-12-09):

#include <Arduino.h>
#include <WiFi.h>
#include <esp_now.h>
#include <esp_wifi.h>
#include <ESP32Servo.h>

// CONFIGURAÇÃO ESP-NOW
uint8_t broadcastAddress[] = {0xA0, 0xDD, 0x6C, 0x85, 0x8A, 0xB8};

// Estrutura para comunicação ESP-NOW
typedef struct struct_message {
    char command[10];
    long value;
    long position;
} struct_message;

struct_message myData;
struct_message receivedData;

// Estruturas para encoders
struct EncoderData {
  volatile long contador;
  volatile int estadoAnterior;
  volatile boolean contadorAtualizado;
  volatile char direcao;
  volatile unsigned long ultimoTempoInterrupcao;
  int pino;
  int* motorDirection;
};

struct Encoder2Data {
  volatile long contador;
  volatile int estadoAnteriorA;
  volatile int estadoAnteriorB;
  volatile boolean contadorAtualizado;
  volatile char direcao;
  volatile unsigned long ultimoTempoInterrupcao;
  int pinoA;
  int pinoB;
  int* motorDirection;
};

// Definições dos pinos de direção - (EIXO Y - ESQUERDA/DIREITA)
#define IN5 33   // Motor C - Sentido 1 (Y)
#define IN6 32   // Motor C - Sentido 2 (Y)

// Definições dos pinos de direção - (EIXO Z - CIMA/BAIXO)
#define IN7 14   // Motor D - Sentido 1 (Z)
#define IN8 13   // Motor D - Sentido 2 (Z)

// Definições dos botões
#define right 25  // Botão direito eixo Y
#define left 26   // Botão esquerdo eixo Y
#define up 12     // Botão cima eixo Z

// Encoders
#define ENCODER_C 27  // Encoder Motor C - Eixo Y (1 canal)
#define ENCODER_D_A 16  // Encoder Motor D - Eixo Z - Canal A
#define ENCODER_D_B 17  // Encoder Motor D - Eixo Z - Canal B

// Garra
#define SERVO_PIN 4

// Variáveis de controle
// Eixo Y
long targetPositionY = 0;
bool movingToTargetY = false;
bool resettingY = false;
int motorDirectionC = 0;

// Eixo Z
long targetPositionZ = 0;
bool movingToTargetZ = false;
bool resettingZ = false;
int motorDirectionD = 0;
const long Z_GROUND_POSITION = 300;

// Garra
Servo gripperServo;
bool gripperOpen = false;

String lastCommand = "STOP";
String lastPrintedCommand = "";

// Encoders instanciados
EncoderData encoderC = {0, 0, false, ' ', 0, ENCODER_C, &motorDirectionC};
Encoder2Data encoderD = {0, 0, 0, false, ' ', 0, ENCODER_D_A, ENCODER_D_B, &motorDirectionD};

const unsigned long DEBOUNCE_TIME = 1;
unsigned long lastButtonTime = 0;
const unsigned long BUTTON_DEBOUNCE = 10;

bool buttonWasPressed = false;
String currentMovement = "";

int gripperTarget = -1;
int gripperCurrent = 80;
unsigned long lastGripperStepTime = 0;
const int GRIP_STEP = 3;
const unsigned long GRIP_STEP_INTERVAL = 50;
unsigned long gripStartTime = 0;
const unsigned long GRIP_TIMEOUT = 1200;
bool gripperMoving = false;

// Flags para enviar ACK fora do callback
bool sendAckPending = false;
struct_message ackData;

// Prototypes
void OnDataSent(const wifi_tx_info_t *info, esp_now_send_status_t status);
void OnDataRecv(const esp_now_recv_info_t *recv_info, const uint8_t *incomingData, int len);

void IRAM_ATTR handleEncoderC();
void IRAM_ATTR handleEncoderD_A();
void IRAM_ATTR handleEncoderD_B();
void updateEncoder(EncoderData &encoder);
void updateEncoder2(Encoder2Data &encoder);
void moveLeft();
void moveRight();
void moveUp();
void moveDown();
void stopMotorsY();
void stopMotorsZ();
void moveToPositionY(long position);
void moveToPositionZ(long position);
void resetY();
void resetZ();
void resetAllEncoders();
void printEncoderStatus();
void stopAllMotors();
void handleButtons();
void updateMotorDirections(int dirC, int dirD);
void controlGripper(int state);
void handleSerialCommands();
void requestGripperMove(int angle);
void processGripperMovementLoop();

// CALLBACKS ESP-NOW
void OnDataSent(const wifi_tx_info_t *info, esp_now_send_status_t status) {
    Serial.print("OnDataSent - status: ");
    Serial.println(status == ESP_NOW_SEND_SUCCESS ? "SUCCESS" : "FAIL");
}

void OnDataRecv(const esp_now_recv_info_t *recv_info, const uint8_t *incomingData, int len) {
    if (len < (int)sizeof(receivedData)) {
        return;
    }
    
    memcpy(&receivedData, incomingData, sizeof(receivedData));
    receivedData.command[sizeof(receivedData.command)-1] = '\0';

    if (strcmp(receivedData.command, "MOVE_Y") == 0) {
        if (receivedData.value == 1) {
            moveLeft();
            movingToTargetY = false;
            resettingY = false;
        } else if (receivedData.value == -1) {
            moveRight();
            movingToTargetY = false;
            resettingY = false;
        }
    }
    else if (strcmp(receivedData.command, "MOVE_Z") == 0) {
        if (receivedData.value == 1) {
            moveUp();
            movingToTargetZ = false;
            resettingZ = false;
        } else if (receivedData.value == -1) {
            moveDown();
            movingToTargetZ = false;
            resettingZ = false;
        }
    }
    else if (strcmp(receivedData.command, "STOP_ALL") == 0) {
        stopAllMotors();
        movingToTargetY = false;
        movingToTargetZ = false;
        resettingY = false;
        resettingZ = false;
    }
    else if (strcmp(receivedData.command, "GOTO_Y") == 0) {
        moveToPositionY(receivedData.position);
    }
    else if (strcmp(receivedData.command, "GOTO_Z") == 0) {
        moveToPositionZ(receivedData.position);
    }
    else if (strcmp(receivedData.command, "RESET_Y") == 0) {
        resetY();
    }
    else if (strcmp(receivedData.command, "RESET_Z") == 0) {
        resetZ();
    }
    else if (strcmp(receivedData.command, "RESET_ENC") == 0) {
        resetAllEncoders();
        memset(&ackData, 0, sizeof(ackData));
        strncpy(ackData.command, "CONFIRM", sizeof(ackData.command)-1);
        ackData.value = 0;
        sendAckPending = true;
    }
    else if (strcmp(receivedData.command, "STATUS") == 0) {
        memset(&ackData, 0, sizeof(ackData));
        strncpy(ackData.command, "STATUS_REQ", sizeof(ackData.command)-1);
        ackData.value = 0;
        sendAckPending = true;
    }
    else if (strcmp(receivedData.command, "GRIP") == 0) {
        requestGripperMove((int)receivedData.value);
    }
}
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

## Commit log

2025-11-16 Codigo para testes basicos de movimentação com 1 esp
2025-11-17 Classificação de objetos
2025-11-22 feat: adicionando yolov11 no projeto, modelo treinado com os pesos para cubos e esferas
    [results.csv]
2025-11-23 feat: retreinando a rede & adicionando código de inferência integrado com a realsense
    [results.csv]
2025-11-23 feat: adicionando novo modelo de treino & novo código de inferência
    [results.csv]
2025-11-25 docs: adiciona entrega prévia de 11/11 com documentação completa da simulação
2025-11-26 Adicionando versão atualizada da garra com camera lateral
2025-11-26 docs: Adicionando readme para explicar os pontos desenvolvidos durante a sprint
2025-11-26 fix: Renomeando arquivo de simulação
2025-12-08 Add 3d models and adjust README
    [tinker.obj]
